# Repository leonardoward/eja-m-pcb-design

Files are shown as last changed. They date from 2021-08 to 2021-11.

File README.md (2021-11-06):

# EJA M v1.0

<p align="center">
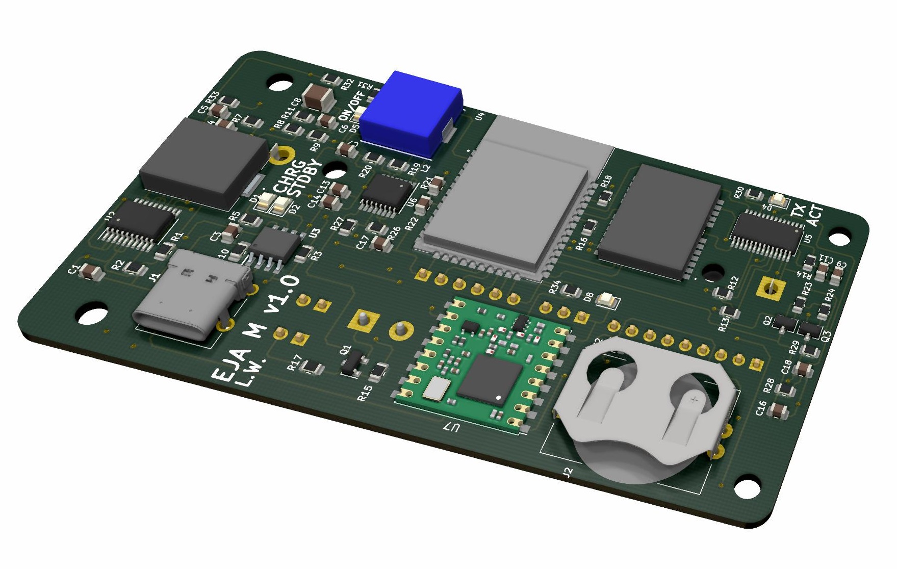
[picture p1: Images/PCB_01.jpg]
  
</p>

The new EJA M v1.0 is an upgrade/replacement of my older PCB designs: [Buoy A v1.0](https://github.com/leonardoward/eja-intelligent-buoy-a-electronics), [Buoy B v1.0](https://github.com/leonardoward/eja-intelligent-buoy-b-electronics), and [Onboard Gateway v1.0](https://github.com/leonardoward/eja-onboard-gateway-electronics). The design includes the following features:

- USB C Port with Electromagnetic Compatibility (EMC)
- FTDI (FT260S-U) with an Auto Reset Circuit for the ESP32
- ESP32
- GPS Module
- LoRa Transceiver
- Real-time Clock (RTC)
- Connector for a Servo Motor
- 5V 2A Stepup (for the Servo Motor)
- 3.3V Battery Charging Circuit
- Connector for a 3 axis accelerometer
- Circuit to measure the battery level
- 3.3V 3A SEPIC Converter
- On-OFF circuit for a Button
- Access to unused pins in the ESP32

This repository contains the Kicad project (including Gerber files) and a more detailed description about the implementation of the different features in the design.

## Table of Contents

1. [Hardware Design](#getting-started)
    1. [USB C Port with Electromagnetic Compatibility EMC](#usb-c-port-with-electromagnetic-compatibility-emc)
    2. [FTDI FT260S](#ftdi-ft260s)
    3. [Auto Reset Circuit for the ESP32](#auto-reset-circuit-for-the-esp32)
    4. [ESP32](#esp32)
    5. [GPS](#gps)
    6. [LoRa](#lora)
    7. [Real time Clock RTC](#real-time-clock-rtc)
    8. [Servo Motor Connector](#servo-motor-connector)
    9. [5V 2A Stepup](#5v-2a-stepup)
    10. [Accelerometer Connector](#accelerometer-connector)
    11. [Battery Charging Circuit](#battery-charging-circuit)
    12. [Battery Level](#battery-level)
    13. [3V3 3A SEPIC Converter](#3v3-3a-sepic-converter)
    14. [ON-OFF Led](#on-off-led)
    15. [ON-OFF Button Circuit](#on-off-button-circuit)
    16. [Extra Header](#extra-header)
2. [PCB Dimensions and Boundaries](#pcb-dimensions-and-boundaries)
3. [3D Model](#3d-model)
4. [Bill of Materials](#bill-of-materials)
    1. [PCB Components](#pcb-components)
    2. [Externals Components](#externals-components)

## Hardware Design

### USB C Port with Electromagnetic Compatibility EMC

Everything starts with the USB C port, we have chosen this type of USB because it's size and because of the growing trend of using this port to charge and communicate with portable devices.

We have included [Transient Voltage Suppression (TVS) diodes](https://www.digikey.com/en/products/detail/comchip-technology/CPDT6-5V4-HF/1121118) and [Ferrite Beads](https://www.digikey.com/en/products/detail/fair-rite-products-corp/2508056017Y0/8594301) to reduce the Electromagnetic Interference (EMI). These [protections for the USB port](https://www.rs-online.com/designspark/usb-port-protection) will add compliance with the [EMC regulations and standards](https://learnemc.com/emc-regulations-and-standards) from the  Federal Communications Commission (FCC) and the European Union.   

<p align="center">
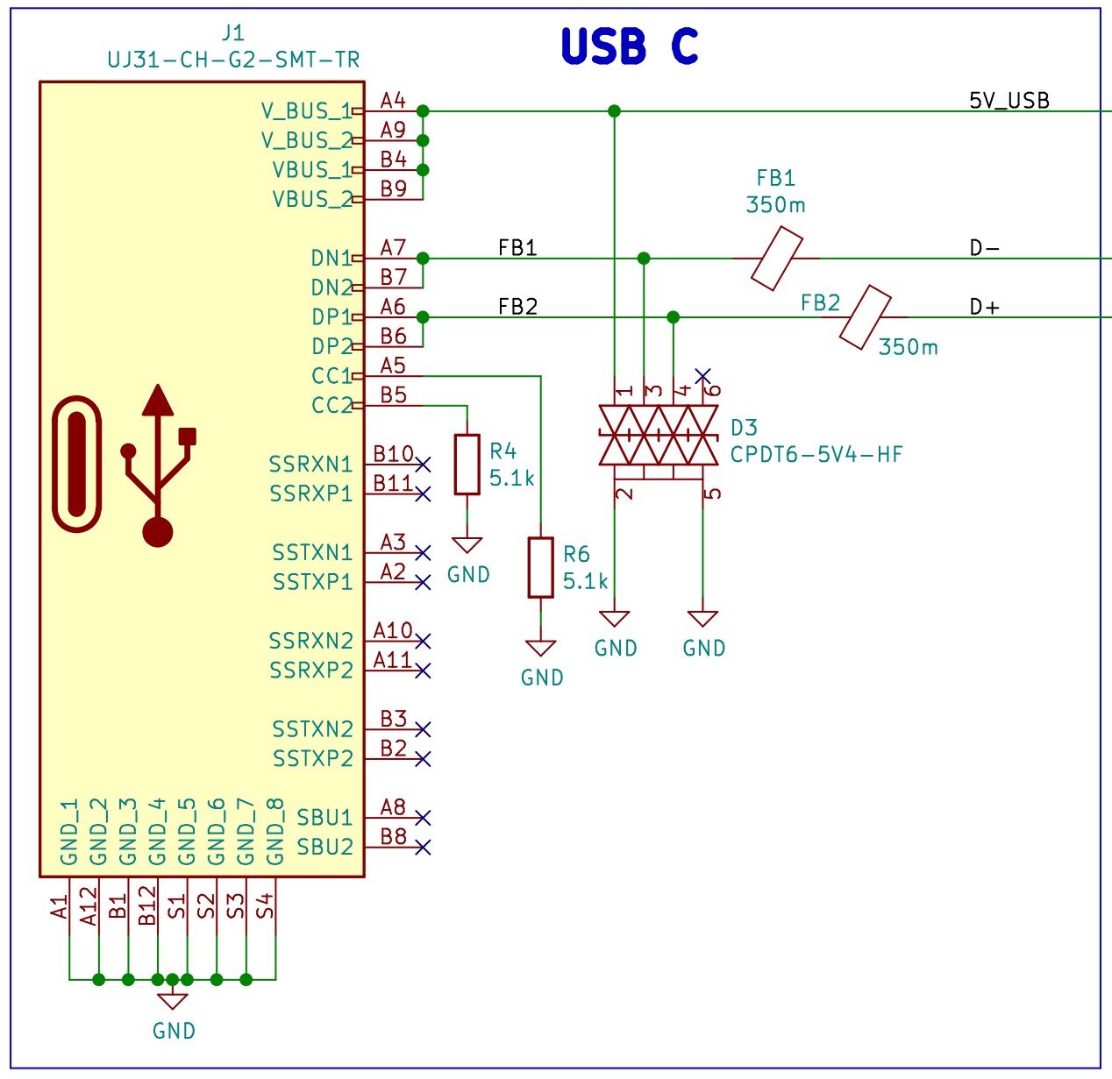
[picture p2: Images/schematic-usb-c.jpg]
  
</p>

**[Back to top](#table-of-contents)**

### FTDI FT260S

The design includes the [FT260S-U](https://www.digikey.com/en/products/detail/ftdi-future-technology-devices-international-ltd/FT260S-U/6124909), a USB TO UART/I2C FTDI that will be used to program the ESP32.

<p align="center">
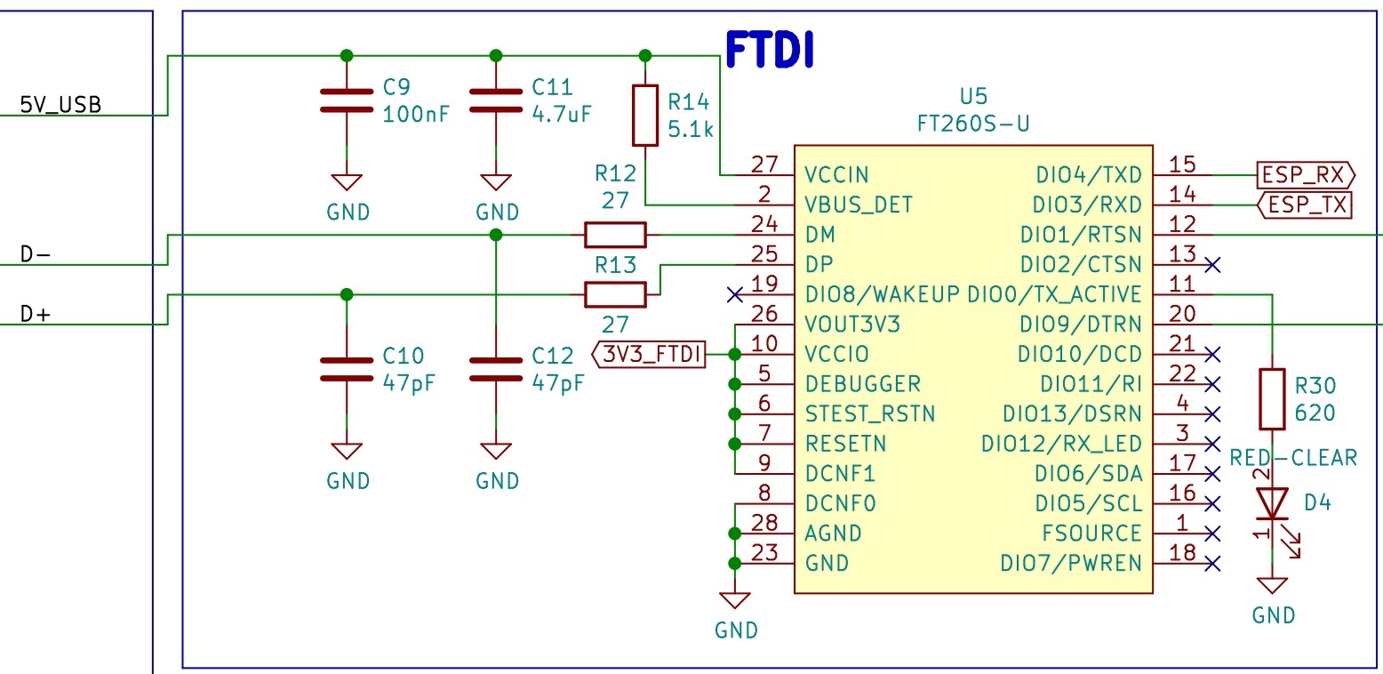
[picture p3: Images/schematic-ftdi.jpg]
  
</p>

**[Back to top](#table-of-contents)**

### Auto Reset Circuit for the ESP32

The design includes an auto reset circuit that uses RTS and DTR to reset and put in bootloader mode the [ESP32](https://www.digikey.com/en/products/detail/espressif-systems/ESP32-WROOM-32D-4MB/9381716). For more information about this circuit, these blogs [(1)](https://forum.micropython.org/viewtopic.php?f=18&t=4966) [(2)](https://forums.adafruit.com/viewtopic.php?f=57&p=483993#p487891) can be useful.

<p align="center">
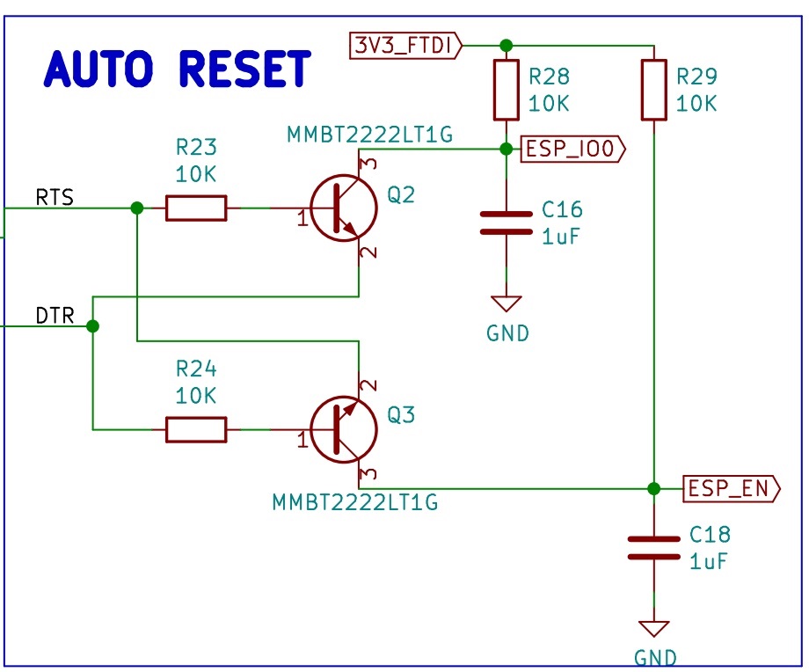
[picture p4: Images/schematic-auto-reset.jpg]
  
</p>

**[Back to top](#table-of-contents)**

### ESP32

The main microcontroller in the PCB is the [ESP32](https://www.digikey.com/en/products/detail/espressif-systems/ESP32-WROOM-32D-4MB/9381716), the following image shows the signals dedicated to the different pins. The ESP32 is connected to the [FTDI](https://www.digikey.com/en/products/detail/ftdi-future-technology-devices-international-ltd/FT260S-U/6124909), a [GPS](https://lcsc.com/product-detail/Satellite-Positioning-Modules_ZHONGKEWEI-ATGM332D-5N31_C128659.html), a [LoRa transceiver](https://www.digikey.com/en/products/detail/rf-solutions/RFM95W-915S2/6564923), a connector for a servo motor, a [real-time clock](https://www.digikey.com/en/products/detail/maxim-integrated/DS3231M-TRL/2402421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), a circuit to measure the battery level, a connector for an [accelerometer](https://www.digikey.com/en/products/detail/adafruit-industries-llc/4097/9951931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), and a few headers to provide access for the unused peripherals.

<p align="center">
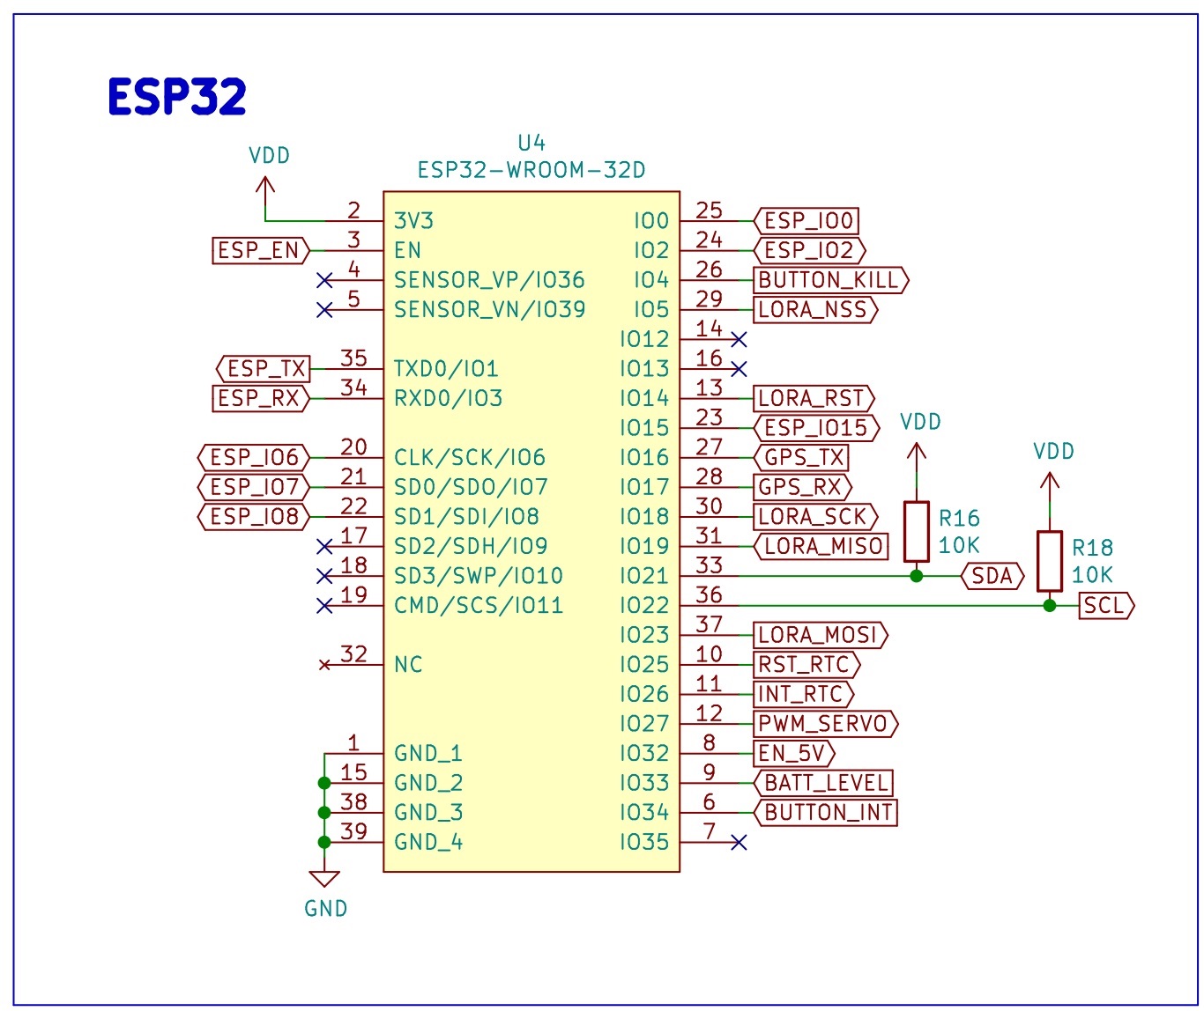
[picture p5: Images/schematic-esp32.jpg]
  
</p>

**[Back to top](#table-of-contents)**

### GPS

The selected GPS is the [ATGM332D-5N31](https://lcsc.com/product-detail/Satellite-Positioning-Modules_ZHONGKEWEI-ATGM332D-5N31_C128659.html), one the modules tested previously in our [Development Board for GPS Modules](https://hackaday.io/project/173457-2021-hdp-dream-team-eja/log/196269-gps-antenova-m20050-1-and-atgm332d-5n31-dev-board). The schematic is very simple, it has a decoupling capacitors (C2), a [U.FL connector](https://www.digikey.com/en/products/detail/hirose-electric-co-ltd/U-FL-R-SMT-1-10/2391570) for an external antenna (J4) and a [Coin Cell Battery Holder](https://www.digikey.com/en/products/detail/linx-technologies-inc/BAT-HLD-001-THM/3044009) (J2).

<p align="center">
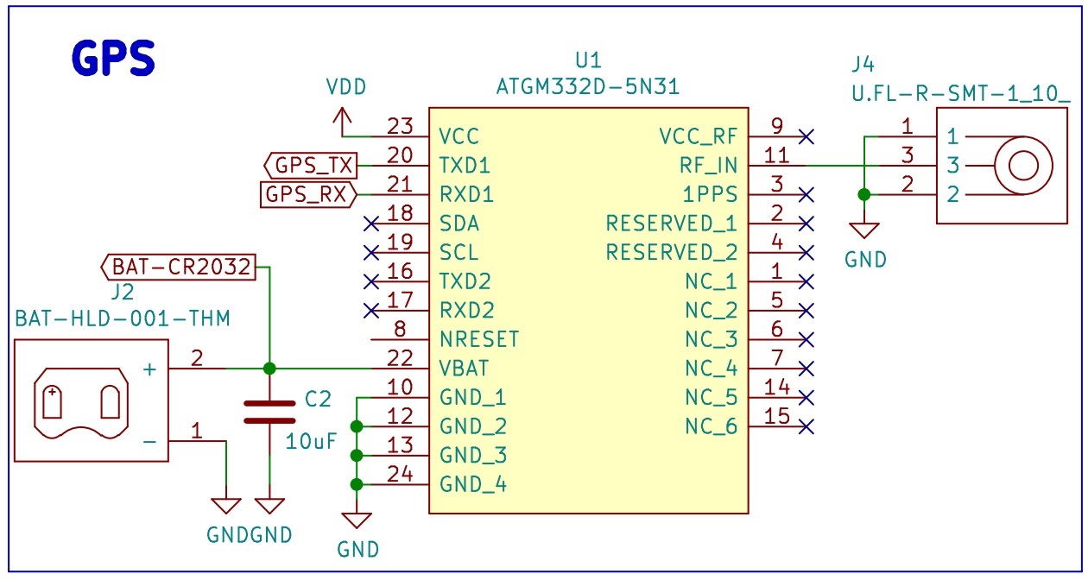
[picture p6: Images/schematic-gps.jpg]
  
</p>

**[Back to top](#table-of-contents)**

### LoRa

The selected LoRa transceiver is the [RFM95W-915S2](https://www.digikey.com/en/products/detail/rf-solutions/RFM95W-915S2/6564923), the same module tested in our [Development Board for LoRa](https://hackaday.io/project/173457-2021-hdp-dream-team-eja/log/196116-lora-rfm95w-915s2-development-board). The schematic contains a [U.FL connector](https://www.digikey.com/en/products/detail/hirose-electric-co-ltd/U-FL-R-SMT-1-10/2391570) for an external antenna (J9).

<p align="center">
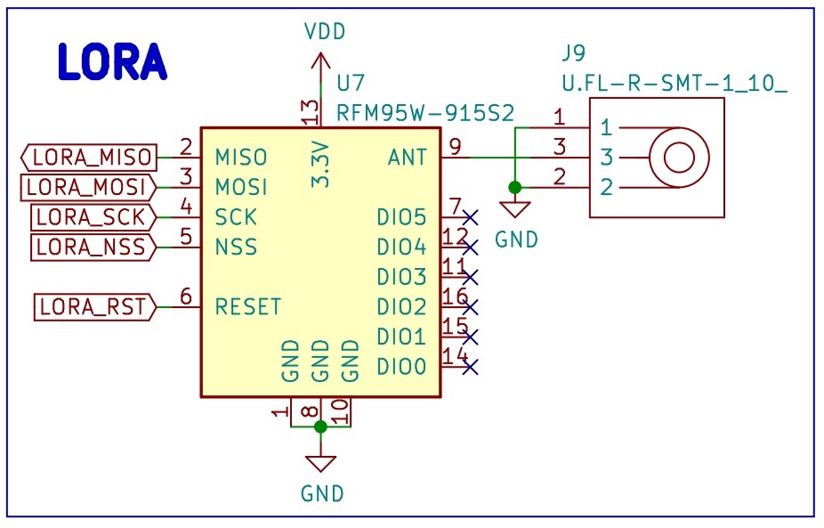
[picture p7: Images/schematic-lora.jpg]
  
</p>

**[Back to top](#table-of-contents)**

### Real time Clock RTC

The design includes a dedicated RTC, the [DS3231M](https://www.digikey.com/en/products/detail/maxim-integrated/DS3231M-TRL/2402421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).

<p align="center">
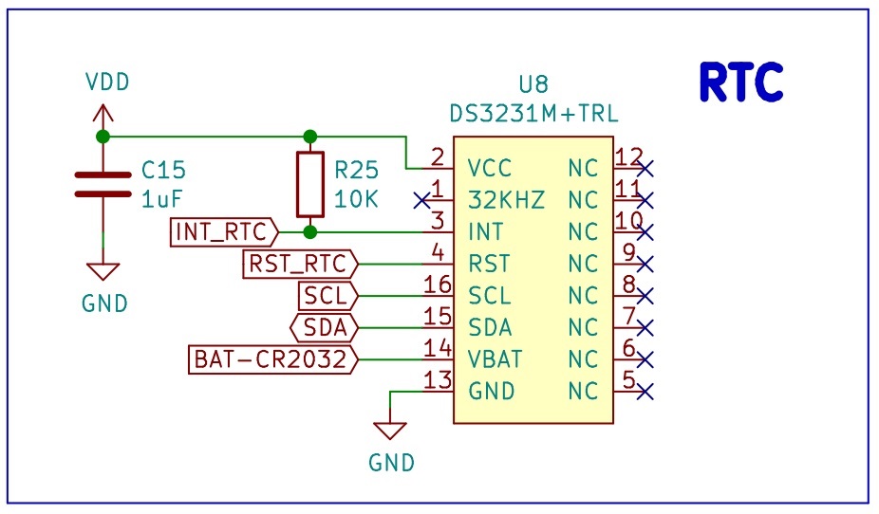
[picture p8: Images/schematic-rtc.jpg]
  
</p>

**[Back to top](#table-of-contents)**

### Servo Motor Connector

There is a 1x3 header connector for a Servo Motor, the 5V for the servo is provided by a 5V 2A Stepup.

<p align="center">
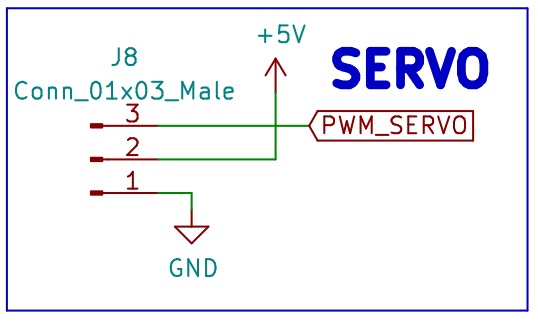
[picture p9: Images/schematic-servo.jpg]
  
</p>

**[Back to top](#table-of-contents)**

### 5V 2A Stepup

The design includes the [TPS61030PWR](http://digikey.com/en/products/detail/texas-instruments/TPS61030PWPR/550685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), a boost converter with a 4A switch current, to provide the 5V for the Servo motor. The schematic contains the components for a 5V 2A output, following the design procedure that starts on the page 13 in the datasheet.

<p align="center">
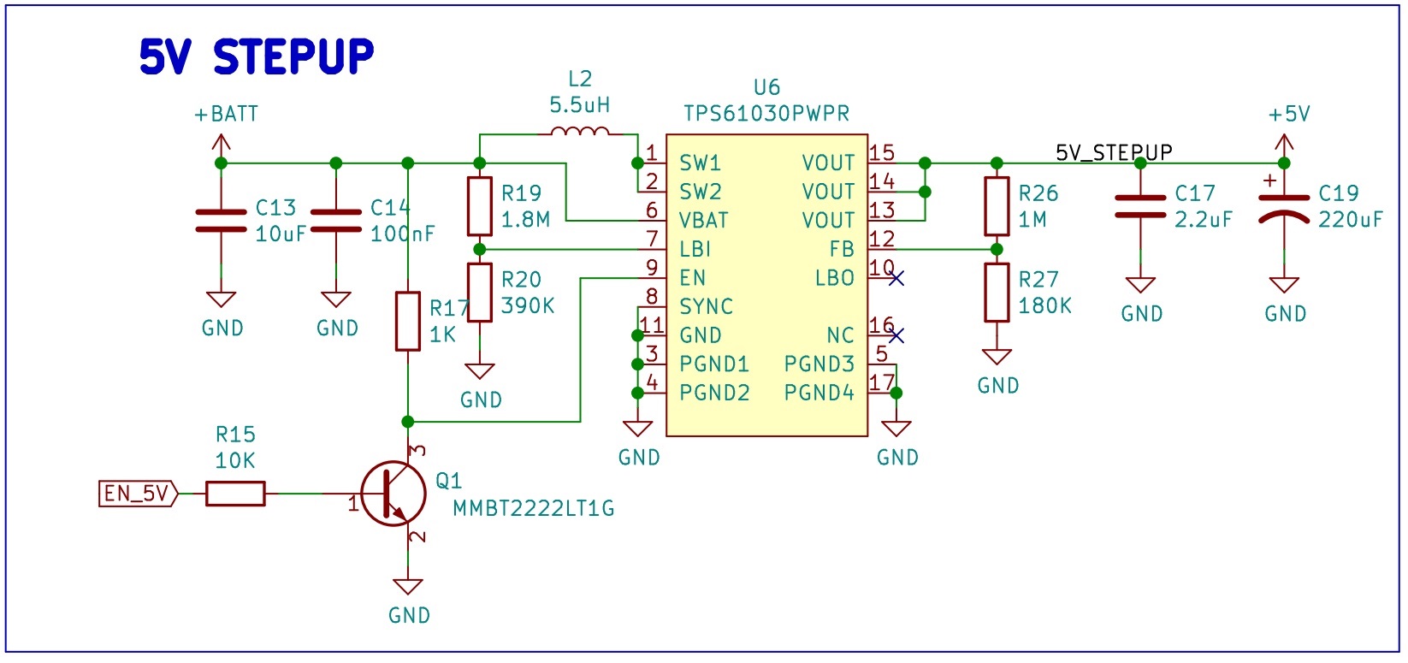
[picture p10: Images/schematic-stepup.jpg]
  
</p>

**[Back to top](#table-of-contents)**

### Accelerometer Connector

There is a connector for the [ADXL343 3 axis accelerometer](https://www.digikey.com/en/products/detail/adafruit-industries-llc/4097/9951931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), a 1x9 header was used even though it only manages the signals VDD, GND, SCL and SDA, in case we want to use more connections for the accelerometer in future versions.

<p align="center">
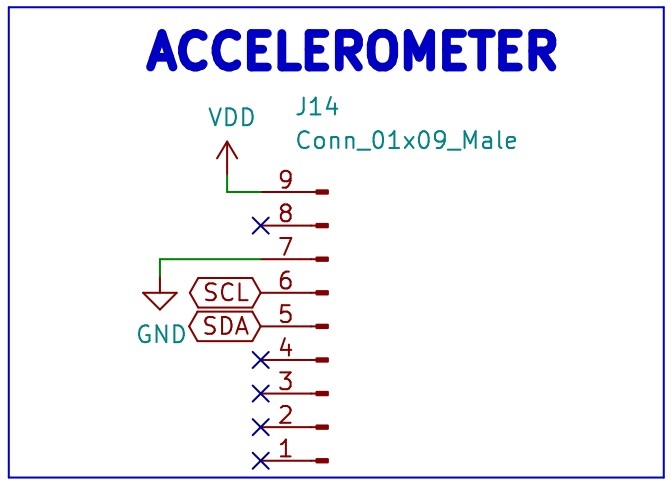
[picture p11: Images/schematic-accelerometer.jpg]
  
</p>

**[Back to top](#table-of-contents)**

### Battery Charging Circuit

To charge the 3.3V battery the design includes the [TP4056](https://www.lcsc.com/product-detail/Battery-Management-ICs_TPOWER-TP4056_C382139.html), a 1A Standalone Linear Li-lon Battery Charger. The schematic includes a green led to show the user that the battery is charged and a red led to show the user that the battery is charging. There is a [Battery Holder for a 18650 battery](https://www.digikey.com/en/products/detail/mpd-memory-protection-devices/BH-18650-PC/3029216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) (J5) and an additional 1x2 header (J7) in case we want to use a different 3.3V battery.  There is also a 1x2 header (J3) to use a different type of connection for the charger (instead of the USB C), for example we can connect and test a QI Wireless Charger.

<p align="center">
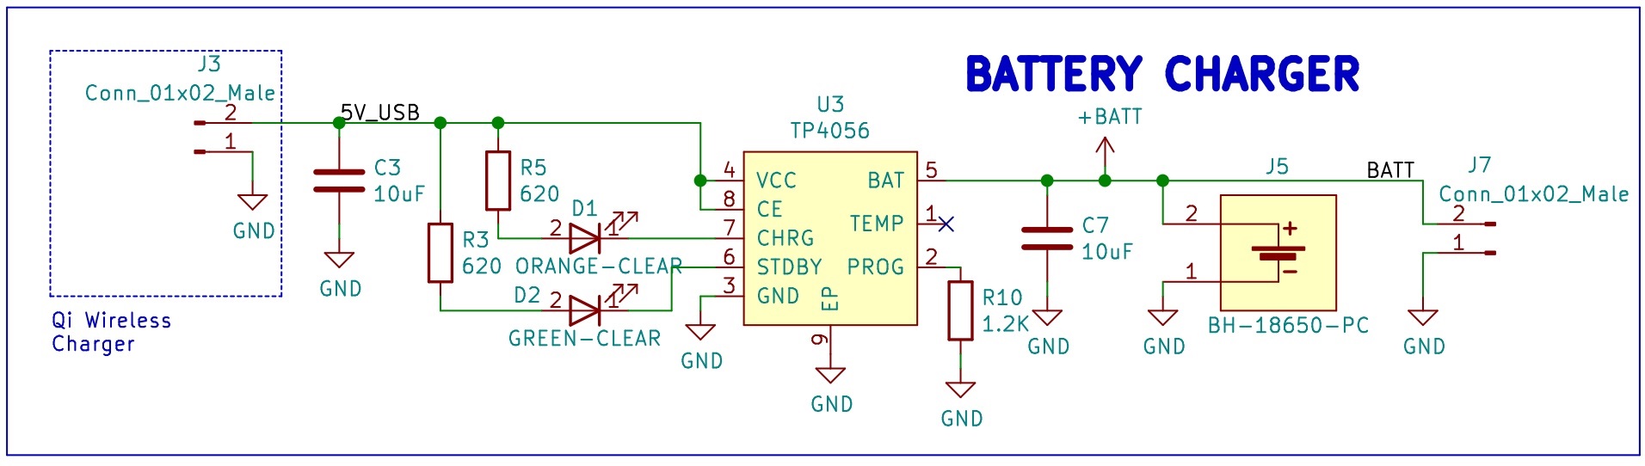
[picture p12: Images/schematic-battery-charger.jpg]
  
</p>

**[Back to top](#table-of-contents)**

### Battery Level

The design contains a circuit to measure a battery level, it is a simple resistor divider calculated for a range of 2.7V to 4.2V, the normal range for the 18650 Li-Ion Battery that will be used in the design.

<p align="center">
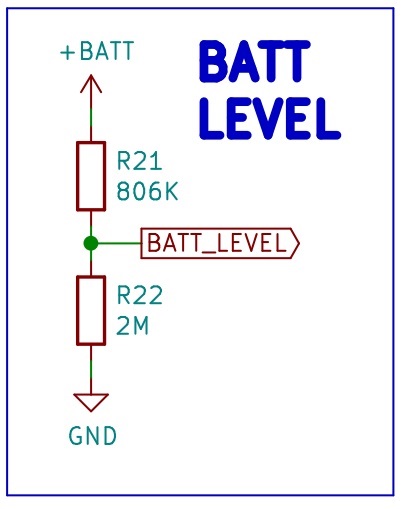
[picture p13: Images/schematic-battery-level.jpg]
  
</p>

Those values for the resistor divider give the following range for the ADC:

- Maximum voltage: 4.2V * (2M / (0.806M + 2M)) = 2.99V
- Minimum voltage: 2.7V * (2M / (0.806M + 2M)) = 1.92V

That means that the ADC from the ESP32 will be reading analog values from 1.92V to 2.99V from the battery measurement circuit.

For more information about measuring lithium battery voltage visit the following [link](https://devzone.nordicsemi.com/nordic/nordic-blog/b/blog/posts/measuring-lithium-battery-voltage-with-nrf52).

**[Back to top](#table-of-contents)**

### 3V3 3A SEPIC Converter

Since the voltage of the battery can change from 2.7V (discharged) to 4.2V (charged), a SEPIC converter is included to provide a constant 3.3V to the digital circuits regardless of the changes in the input voltage from the battery. The selected SEPIC converter is the [LTC3113EFE#TRPBF](https://www.digikey.com/en/products/detail/analog-devices-inc/LTC3113EFE-TRPBF/2521714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).

<p align="center">
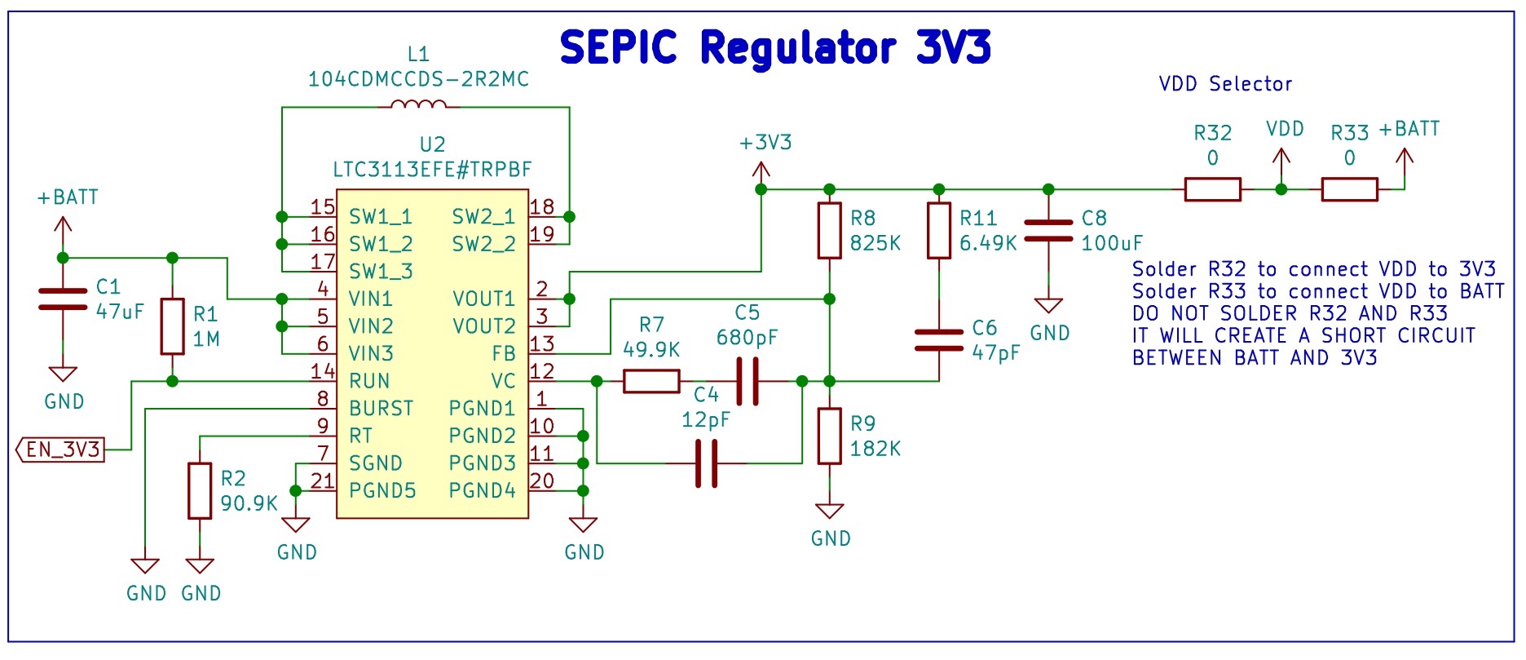
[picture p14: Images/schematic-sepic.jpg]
  
</p>

**Note**: The resistor R32 is a jumper that connects VDD to 3V3. R33 is a jumper that connects VDD to the battery. Do not solder both at the same time, it will create a short circuit between 3.3V from the SEPIC and the voltage from the battery. R32 and R33 are included just in case the SEPIC converter doesn't work and we have to connect the circuit directly to the battery.

**Summary: Do not solder R33**.

**[Back to top](#table-of-contents)**

### ON-OFF Led

There is  Green Led that turns on with the 3.3V from the SEPIC converter, it will notify the user/developer that the device is ON or OFF.

<p align="center">
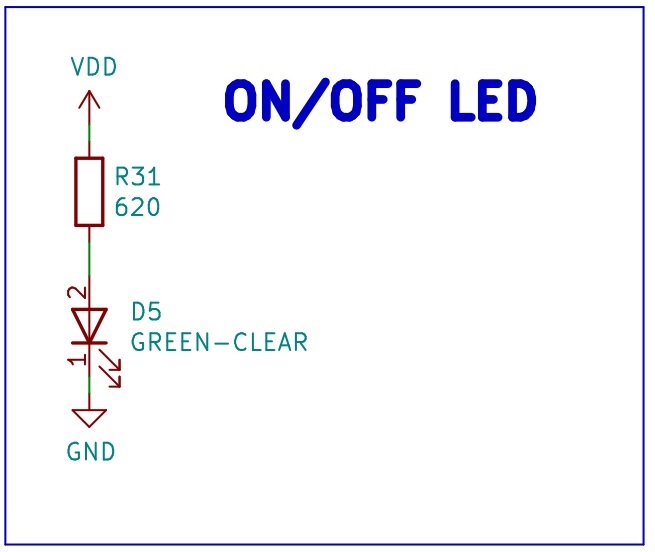
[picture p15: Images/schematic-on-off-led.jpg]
  
</p>

**[Back to top](#table-of-contents)**

### ON-OFF Button Circuit

The design contains a [LTC2954ITS8-1#TRPBF](https://www.digikey.com/en/products/detail/analog-devices-inc/LTC2954ITS8-1-TRPBF/1621452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), a pushbutton ON/OFF controller that manages the power supply (enables the 3.3V SEPIC) via a pushbutton interface.

<p align="center">
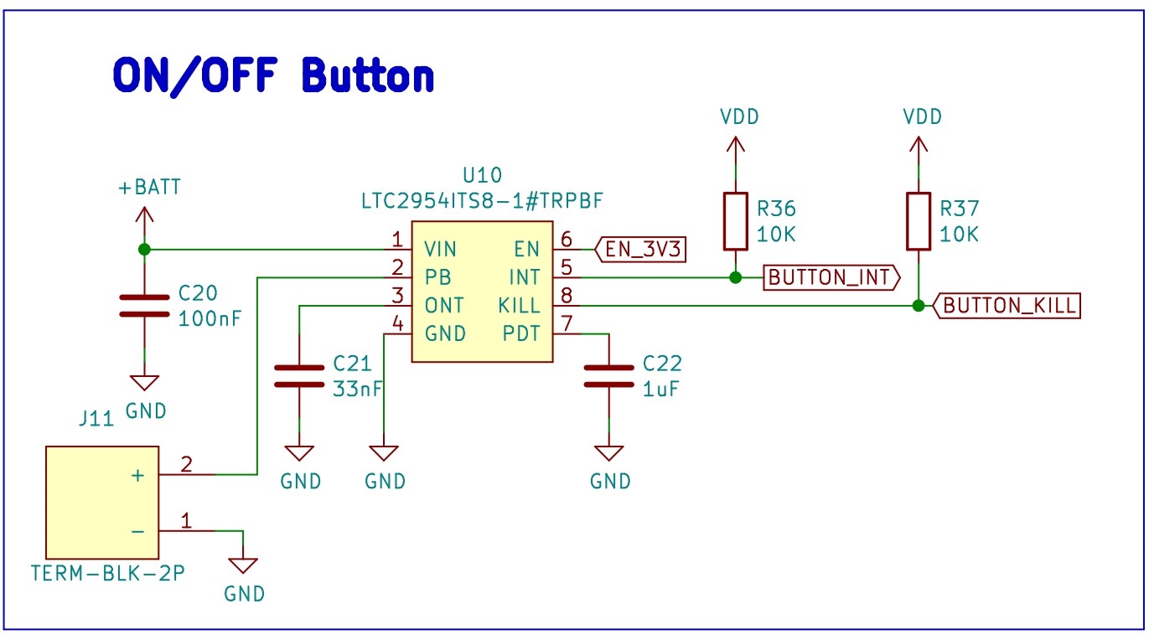
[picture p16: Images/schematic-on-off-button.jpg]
  
</p>

**[Back to top](#table-of-contents)**

### Extra Header

The design includes an 1x06 header to provide access for some of the unused pins in the ESP32.

<p align="center">
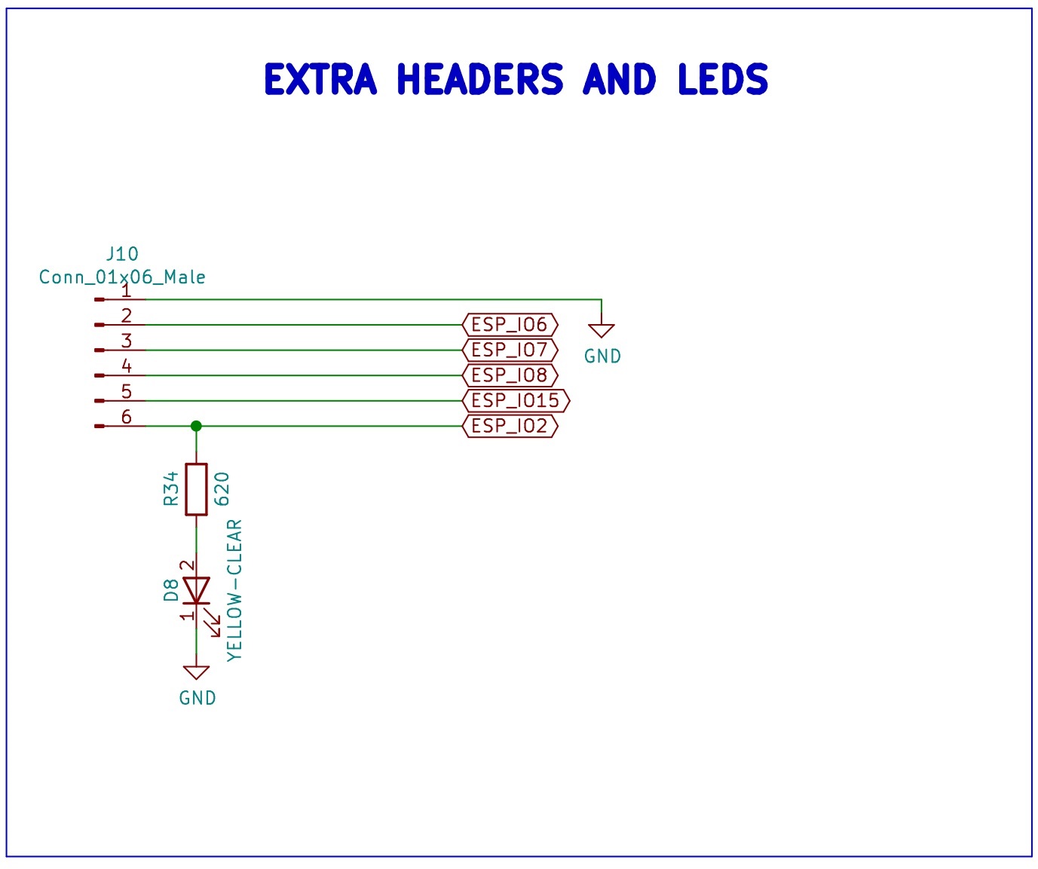
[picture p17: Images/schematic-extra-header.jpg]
  
</p>

**[Back to top](#table-of-contents)**

## PCB Dimensions and Boundaries

The dimensions of the PCB are dictated by the maximum available space inside the buoy, from the enclosure design we where able to define the size of the PCB: 97.5 mm x 51.2 mm.

In the back layer there is a restricted region, that can't contain any components because the PCB is directly in contact with the enclosure in that region, those are the boundaries of the back layer. Through hole footprints where not be placed in that section, even if the footprint is placed in the front layer.

<p align="center">
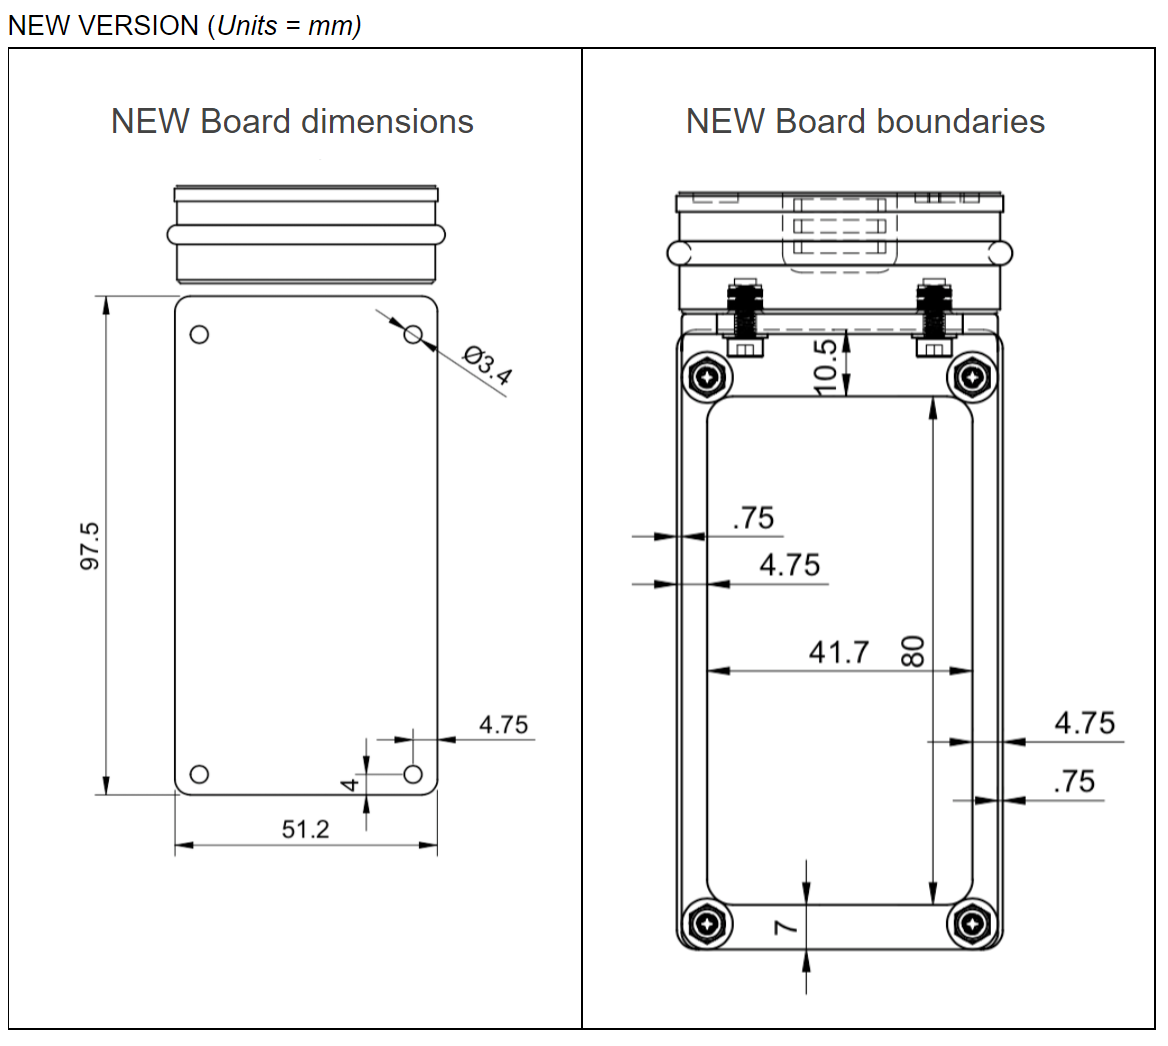
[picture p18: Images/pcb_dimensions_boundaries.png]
  
</p>

**[Back to top](#table-of-contents)**

## 3D Model

The following images show the front and back layers of the PCB.

<p align="center">
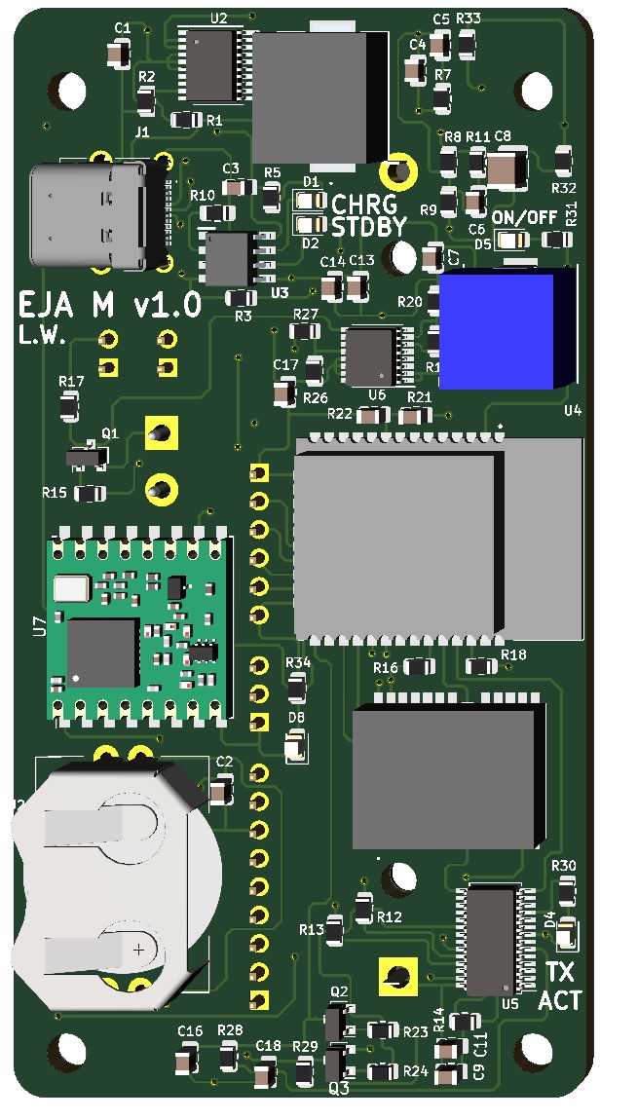
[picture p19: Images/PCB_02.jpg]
  
</p>

<p align="center">
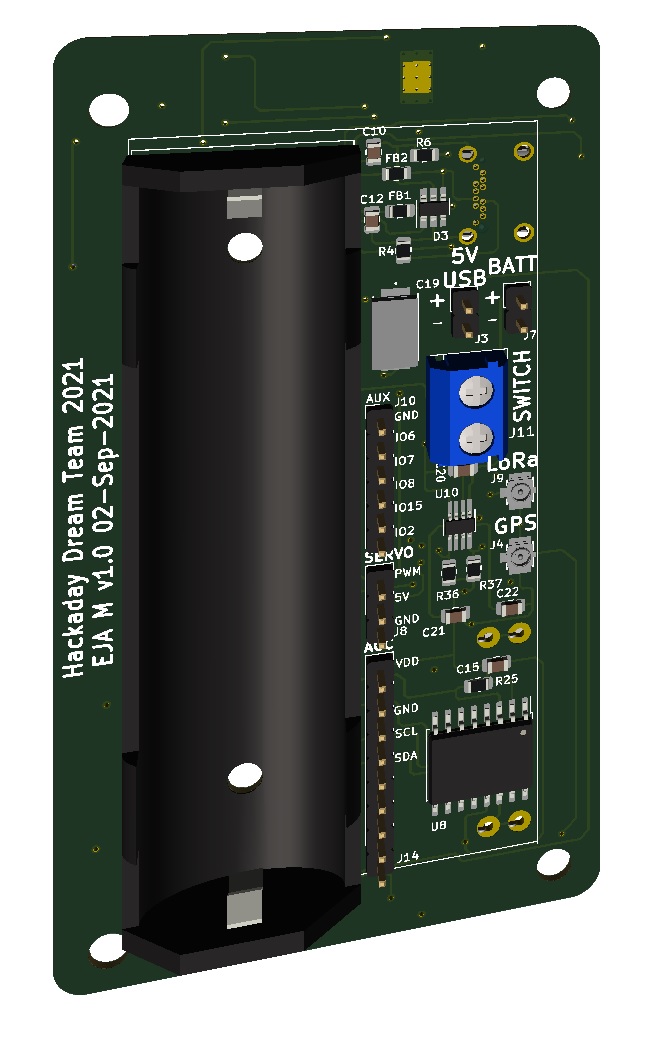
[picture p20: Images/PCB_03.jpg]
  
</p>

**[Back to top](#table-of-contents)**

## Bill of Materials

### PCB Components

| Reference | Quantity |
| --- | --- |
| [PCB](https://www.pcbway.com/)  | 1 |
| [47 µF ±20% 6.3V Ceramic Capacitor 0805](https://www.digikey.com/en/products/detail/taiyo-yuden/JMK212BBJ476MG-T/4970731)  | 1 |
| [10 µF ±10% 6.3V Ceramic Capacitor 0805](https://www.digikey.com/en/products/detail/samsung-electro-mechanics/CL21A106KQCLNNC/3888062)  | 4 |
| [12 pF ±5% 50V Ceramic Capacitor 0805](https://www.digikey.com/en/products/detail/stackpole-electronics-inc/CML0805C0G120JT50V/10660016)  | 1 |
| [680 pF ±10% 25V Ceramic Capacitor 0805](https://www.digikey.com/en/products/detail/w%C3%BCrth-elektronik/885012207059/5455614)  | 1 |
| [47 pF ±5% 16V Ceramic Capacitor 0805](https://www.digikey.com/en/products/detail/w%C3%BCrth-elektronik/885012007014/5453673)  | 3 |
| [100 µF ±20% 6.3V Ceramic Capacitor 1210](https://www.digikey.com/en/products/detail/murata-electronics/GRM32EE70J107ME15L/5027618)  | 1 |
| [0.1 µF ±10% 50V Ceramic Capacitor 0805](https://www.digikey.com/en/products/detail/avx-corporation/08055C104KAT2A/563505)  | 3 |
| [4.7 µF ±10% 6.3V Ceramic Capacitor 0805](https://www.digikey.com/en/products/detail/samsung-electro-mechanics/CL21A475KQFNNNE/3886856)  | 1 |
| [1 µF ±10% 16V Ceramic Capacitor 0805](https://www.digikey.com/en/products/detail/yageo/CC0805KKX7R7BB105/2103103)  | 4 |
| [2.2 µF ±10% 10V Ceramic Capacitor 0805](https://www.digikey.com/en/products/detail/samsung-electro-mechanics/CL21B225KPFNNNE/3886846)  | 1 |
| [220 µF Tantalum Capacitors 10V 2917](https://www.digikey.com/en/products/detail/nemco/PCT220-10HK/13236441)  | 1 |
| [0.033 µF ±10% 50V Ceramic Capacitor 0805](https://www.digikey.com/en/products/detail/w%C3%BCrth-elektronik/885012207095/5453932)  | 1 |
| [Orange 601nm LED - Discrete 2.1V 0805](https://www.digikey.com/en/products/detail/sunled/XZMOK54W-1/4745796)  | 1 |
| [Green 520nm LED - Discrete 3.2V 0805](https://www.digikey.com/en/products/detail/w%C3%BCrth-elektronik/150080GS75000/4489915)  | 2 |
| [TVS Diode 15V Clamp 5A (8/20µs) SOT-23-6](https://www.digikey.com/en/products/detail/comchip-technology/CPDT6-5V4-HF/1121118)  | 1 |
| [Red 630nm LED - Discrete 1.9V 0805](https://www.digikey.com/en/products/detail/w%C3%BCrth-elektronik/150080SS75000/4489921)  | 1 |
| [Yellow 590nm LED - Discrete 2V 0805](https://www.digikey.com/en/products/detail/everlight-electronics-co-ltd/QTLP630C3TR/2675901)  | 1 |
| [1 Signal Line Ferrite Bead 0805 300mA 350mOhm](https://www.digikey.com/en/products/detail/fair-rite-products-corp/2508056017Y0/8594301)  | 2 |
| [USB-C USB 3.2 Gen 2 Receptacle Connector](https://www.digikey.com/en/products/detail/cui-devices/UJ31-CH-G2-SMT-TR/8024057)  | 1 |
| [Battery Retainer Coin, 20.0mm 1 Cell PC Pin](https://www.digikey.com/en/products/detail/linx-technologies-inc/BAT-HLD-001-THM/3044009)  | 1 |
| [U.FL (UMCC) Connector Receptacle](https://www.digikey.com/en/products/detail/hirose-electric-co-ltd/U-FL-R-SMT-1-10/2391570)  | 2 |
| [Battery Holder (Open) 18650 1 Cell PC Pin](https://www.digikey.com/en/products/detail/mpd-memory-protection-devices/BH-18650-PC/3029216)  | 1 |
| [2 Position Terminal Block Horizontal](https://www.digikey.com/en/products/detail/on-shore-technology-inc/OSTTC022162/614558)  | 1 |
| [2.2 µH Inductor 15 A 7mOhm Max](https://www.digikey.com/en/products/detail/sumida-america-components-inc/104CDMCCDS-2R2MC/5812436)  | 1 |
| [5.5 µH Inductor 10 A 10.3mOhm](https://www.digikey.com/en/products/detail/w%C3%BCrth-elektronik/744325550/1638576)  | 1 |
| [Bipolar (BJT) Transistor NPN 30V 600mA SOT-23-3](https://www.digikey.com/en/products/detail/onsemi/MMBT2222LT1G/919595)  | 3 |
| [1 MOhms ±1% 0.125W Chip Resistor 0805](https://www.digikey.com/en/products/detail/stackpole-electronics-inc/RMCF0805FT1M00/1760080)  | 2 |
| [90.9 kOhms ±1% 0.125W Chip Resistor 0805](https://www.digikey.com/en/products/detail/stackpole-electronics-inc/RMCF0805FT90K9/1760265)  | 1 |
| [620 Ohms ±5% 0.125W Chip Resistor 0805](https://www.digikey.com/en/products/detail/yageo/RC0805JR-07620RL/728357)  | 5 |
| [5.1 KOhms ±1% 0.125W Chip Resistor 0805](https://www.digikey.com/en/products/detail/stackpole-electronics-inc/RMCF0805FT5K10/1760394)  | 3 |
| [49.9 KOhms ±1% 0.125W Chip Resistor 0805](https://www.digikey.com/en/products/detail/stackpole-electronics-inc/RMCF0805FT49K9/1760272)  | 1 |
| [825 kOhms ±0.5% 0.125W Chip Resistor 0805](https://www.digikey.com/en/products/detail/panasonic-electronic-components/ERA-6AED8253V/3481309)  | 1 |
| [182 kOhms ±1% 0.25W Chip Resistor 0805](https://www.digikey.com/en/products/detail/koa-speer-electronics-inc/RK73H2ATTD1823F/10234151)  | 1 |
| [1.2 kOhms ±5% 0.125W Chip Resistor 0805](https://www.digikey.com/en/products/detail/yageo/RC0805JR-071K2L/728224)  | 1 |
| [6.49 kOhms ±1% 0.125W Chip Resistor 0805](https://www.digikey.com/en/products/detail/panasonic-electronic-components/ERJ-6ENF6491V/111437)  | 1 |
| [27 Ohms ±1% 0.125W Chip Resistor 0805](https://www.digikey.com/en/products/detail/stackpole-electronics-inc/RMCF0805FT27R0/1712920)  | 2 |
| [10 kOhms ±1% 0.125W Chip Resistor 0805](https://www.digikey.com/en/products/detail/vishay-dale/CRCW080510K0FKEAC/7928398)  | 10 |
| [1 kOhms ±1% 0.125W Chip Resistor 0805](https://www.digikey.com/en/products/detail/stackpole-electronics-inc/RMCF0805FT1K00/1760090)  | 1 |
| [1.8 MOhms ±1% 0.125W Chip Resistor 0805](https://www.digikey.com/en/products/detail/panasonic-electronic-components/ERJ-6ENF1804V/282715)  | 1 |
| [390 kOhms ±1% 0.125W Chip Resistor 0805](https://www.digikey.com/en/products/detail/yageo/RC0805FR-07390KL/727903)  | 1 |
| [806 kOhms ±1% 0.125W Chip Resistor 0805](https://www.digikey.com/en/products/detail/panasonic-electronic-components/ERJ-6ENF8063V/112197)  | 1 |
| [2 MOhms ±1% 0.125W Chip Resistor 0805](https://www.digikey.com/en/products/detail/vishay-dale/CRCW08052M00FKECC/7928551)  | 1 |
| [180 kOhms ±0.5% 0.1W Chip Resistor 0805](https://www.digikey.com/en/products/detail/susumu/RR1220P-184-D/432345)  | 1 |
| [0 Ohms Jumper 0.125W Chip Resistor 0805](https://www.digikey.com/en/products/detail/yageo/RC0805JR-070RL/728216)  | 2 |
| [ATGM332D-5N31 GNSS Series GPS+BDS 12.2x16x2.4mm](https://www.lcsc.com/product-detail/Satellite-Positioning-Modules_ZHONGKEWEI-ATGM332D-5N31_C128659.html)  | 1 |
| [Buck-Boost Switching Regulator 1.8V 1 Output 3A](https://www.digikey.com/en/products/detail/analog-devices-inc/LTC3113EFE-TRPBF/2521714)  | 1 |
| [TP4056 ESOP-8 Battery Management](https://www.lcsc.com/product-detail/Battery-Management-ICs_TPOWER-TP4056_C382139.html)  | 1 |
| [ESP32-WROOM-32D (4MB)](https://www.digikey.com/en/products/detail/espressif-systems/ESP32-WROOM-32D-4MB/9381716)  | 1 |
| [FTDI USB Bridge, USB to I²C/UART USB 2.0 I²C, UART Interface 28-TSSOP](https://www.digikey.com/en/products/detail/ftdi-future-technology-devices-international-ltd/FT260S-U/6124909)  | 1 |
| [TPS61030PWPR Boost Switching Regulator IC Positive Adjustable 1.8V 1 Output 3.6A (Switch)](https://www.digikey.com/en/products/detail/texas-instruments/TPS61030PWPR/550685)  | 1 |
| [RFM95W-915S2-ND LoRa Transceiver Module 915MHz](https://www.digikey.com/en/products/detail/rf-solutions/RFM95W-915S2/6564923)  | 1 |
| [DS3231M+TRL Real Time Clock I²C, 2-Wire Serial](https://www.digikey.com/en/products/detail/maxim-integrated/DS3231M-TRL/2402421)  | 1 |
| [Power Supply On/Off Controller Push Button](https://www.digikey.com/en/products/detail/analog-devices-inc/LTC2954ITS8-1-TRPBF/1621452)  | 1 |
| [Connector Header Through Hole 40 position (2.54mm)](https://www.digikey.com/en/products/detail/sullins-connector-solutions/PREC040SFAN-RC/2774934)  | 1 |

### Externals Components

| Reference | Quantity |
| --- | --- |
| [SERVOMOTOR RC 5V HIGH TORQUE](https://www.digikey.com/products/es?keywords=1528-1084-ND)  | 1 |
| [CR2032 Lithium Coin Cell Battery](https://www.adafruit.com/product/654)  | 1 |
| [18650 Lithium-Ion 3.7V Battery Rechargeable 3.4Ah](https://www.digikey.com/en/products/detail/ultralast/LION-1865-34/13692714)  | 1 |
| [ADXL343 - Triple-Axis Accelerometer](https://www.digikey.com/en/products/detail/adafruit-industries-llc/4097/9951931)  | 1 |

For more information about the BOM including prices and different comparisons with my previous designs visit the following [link](https://hackaday.io/project/173457-2021-hdp-dream-team-eja/log/198071-eja-m-v10-bill-of-materials).

**[Back to top](#table-of-contents)**

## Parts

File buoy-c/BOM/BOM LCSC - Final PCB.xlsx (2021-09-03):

Reference | Quantity | LCSC Part Number
TP4056 | 4 | C382139
ESP32-WROOM-32D | 2 | C473012

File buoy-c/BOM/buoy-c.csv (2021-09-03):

Source: | C:\Ext\Dream Team 2021\eja-buoy-c-pcb-design\buoy-c\buoy-c.sch
Date: | 02-Sep-21 10:00:40 AM
Tool: | Eeschema (5.1.10)-1
Generator: | C:\Program Files\KiCad\bin\scripting\plugins/bom_csv_grouped_by_value.py
Component Count: | 91
Individual Components:
Item | Qty | Reference(s) | Value | LibPart | Footprint | Datasheet | Description | Field7 | Height | LCSC | Manufacturer | Manufacturer Name | Manufacturer Part Number | Manufacturer_Name | Manufacturer_Part_Number | Supplier 1 | Supplier 2 | Supplier Part Number 1 | Supplier Part Number 2
 |  | C1 | 47uF | C-47uF-0805:47uF | Capacitor_SMD:C_0805_2012Metric | https://www.yuden.co.jp/productdata/catalog/mlcc06_e.pdf |  |  |  |  | Taiyo Yuden |  | JMK212BBJ476MG-T |  |  | Digi-Key |  | 587-4280-1-ND
 |  | C2 | 10uF | C-10uF-0805:10uF | Capacitor_SMD:C_0805_2012Metric |  |  |  |  |  | Samsung Electro-Mechanics |  | CL21A106KQCLNNC |  |  | Digi-Key |  | 1276-2404-1-ND
 |  | C3 | 10uF | C-10uF-0805:10uF | Capacitor_SMD:C_0805_2012Metric |  |  |  |  |  | Samsung Electro-Mechanics |  | CL21A106KQCLNNC |  |  | Digi-Key |  | 1276-2404-1-ND
 |  | C4 | 12pF | C-12pF-0805:12pF | Capacitor_SMD:C_0805_2012Metric | http://www.seielect.com/Catalog/SEI-CML.PDF |  |  |  |  | Stackpole Electronics Inc |  | CML0805C0G120JT50V |  |  | Digi-Key |  | 738-CML0805C0G120JT50VCT-ND
 |  | C5 | 680pF | C-680pF-0805:680pF | Capacitor_SMD:C_0805_2012Metric | https://www.we-online.de/katalog/datasheet/885012207059.pdf |  |  |  |  | Würth Elektronik |  | 885012207059 |  |  | Digi-Key |  | 732-12279-1-ND
 |  | C6 | 47pF | C-47pF-0805:47pF | Capacitor_SMD:C_0805_2012Metric | https://www.we-online.de/katalog/datasheet/885012007014.pdf |  |  |  |  | Würth Elektronik |  |  |  | 885012007014 | Digi-Key |  | 732-7818-1-ND
 |  | C7 | 10uF | C-10uF-0805:10uF | Capacitor_SMD:C_0805_2012Metric |  |  |  |  |  | Samsung Electro-Mechanics |  | CL21A106KQCLNNC |  |  | Digi-Key |  | 1276-2404-1-ND
 |  | C8 | 100uF | C-100uF-1210:100uF | Capacitor_SMD:C_1210_3225Metric | https://search.murata.co.jp/Ceramy/image/img/A01X/G101/ENG/GRM32EE70J107ME15-01.pdf |  |  |  |  | Murata Electronics |  | GRM32EE70J107ME15L |  |  | Digi-Key |  | 490-10534-1-ND
 |  | C9 | 100nF | C-100nF-0805:100nF | Capacitor_SMD:C_0805_2012Metric | https://datasheets.avx.com/X7RDielectric.pdf |  |  |  |  | AVX Corporation |  |  |  | 08055C104KAT2A | Digi-Key |  | 478-1395-1-ND
 |  | C10 | 47pF | C-47pF-0805:47pF | Capacitor_SMD:C_0805_2012Metric | https://www.we-online.de/katalog/datasheet/885012007014.pdf |  |  |  |  | Würth Elektronik |  |  |  | 885012007014 | Digi-Key |  | 732-7818-1-ND
 |  | C11 | 4.7uF | C-4.7uF-0805:4.7uF | Capacitor_SMD:C_0805_2012Metric | http://www.samsungsem.com/kr/support/product-search/mlcc/CL21A475KQFNNNE.jsp |  |  |  |  | Samsung Electro-Mechanics |  |  |  | CL21A475KQFNNNE | Digi-Key |  | 1276-1198-1-ND
 |  | C12 | 47pF | C-47pF-0805:47pF | Capacitor_SMD:C_0805_2012Metric | https://www.we-online.de/katalog/datasheet/885012007014.pdf |  |  |  |  | Würth Elektronik |  |  |  | 885012007014 | Digi-Key |  | 732-7818-1-ND
 |  | C13 | 10uF | C-10uF-0805:10uF | Capacitor_SMD:C_0805_2012Metric |  |  |  |  |  | Samsung Electro-Mechanics |  | CL21A106KQCLNNC |  |  | Digi-Key |  | 1276-2404-1-ND
 |  | C14 | 100nF | C-100nF-0805:100nF | Capacitor_SMD:C_0805_2012Metric | https://datasheets.avx.com/X7RDielectric.pdf |  |  |  |  | AVX Corporation |  |  |  | 08055C104KAT2A | Digi-Key |  | 478-1395-1-ND
 |  | C15 | 1uF | C-1uF-0805:1uF | Capacitor_SMD:C_0805_2012Metric | http://www.samsungsem.com/kr/support/product-search/mlcc/CL21B105KPFNNNE.jsp |  |  |  |  | YAGEO |  | CC0805KKX7R7BB105 |  | CL21B105KPFNNNE | Digi-Key |  | 311-1365-1-ND
 |  | C16 | 1uF | C-1uF-0805:1uF | Capacitor_SMD:C_0805_2012Metric | http://www.samsungsem.com/kr/support/product-search/mlcc/CL21B105KPFNNNE.jsp |  |  |  |  | YAGEO |  | CC0805KKX7R7BB105 |  | CL21B105KPFNNNE | Digi-Key |  | 311-1365-1-ND
 |  | C17 | 2.2uF | C-2.2uF-0805:2.2uF | Capacitor_SMD:C_0805_2012Metric | http://www.samsungsem.com/kr/support/product-search/mlcc/CL21B225KPFNNNE.jsp |  |  |  |  | Samsung Electro-Mechanics |  | CL21B225KPFNNNE |  |  | Digi-Key |  | 1276-1188-1-ND
 |  | C18 | 1uF | C-1uF-0805:1uF | Capacitor_SMD:C_0805_2012Metric | http://www.samsungsem.com/kr/support/product-search/mlcc/CL21B105KPFNNNE.jsp |  |  |  |  | YAGEO |  | CC0805KKX7R7BB105 |  | CL21B105KPFNNNE | Digi-Key |  | 311-1365-1-ND
 |  | C19 | 220uF | C-220uF-2917:220uF | C-2917-7343-Metric:C-2917-7343-Metric | https://suntsu.com/wp-content/uploads/2020/10/NEMCO_PCT-Series_10.19.2020.pdf |  |  |  |  | Nemco |  | PCT220/10HK |  |  | Digi-Key |  | 2388-PCT220/10HK-ND
 |  | C20 | 100nF | C-100nF-0805:100nF | Capacitor_SMD:C_0805_2012Metric | https://datasheets.avx.com/X7RDielectric.pdf |  |  |  |  | AVX Corporation |  |  |  | 08055C104KAT2A | Digi-Key |  | 478-1395-1-ND
 |  | C21 | 33nF | C-33nF-0805:33nF | Capacitor_SMD:C_0805_2012Metric | https://www.we-online.de/katalog/datasheet/885012207095.pdf |  |  |  |  | Würth Elektronik |  | 885012207095 |  |  | Digi-Key |  | 732-8077-1-ND
 |  | C22 | 1uF | C-1uF-0805:1uF | Capacitor_SMD:C_0805_2012Metric | http://www.samsungsem.com/kr/support/product-search/mlcc/CL21B105KPFNNNE.jsp |  |  |  |  | YAGEO |  | CC0805KKX7R7BB105 |  | CL21B105KPFNNNE | Digi-Key |  | 311-1365-1-ND
 |  | D1 | ORANGE-CLEAR | LED-ORANGE-CLEAR-0805:ORANGE-CLEAR | LED_SMD:LED_0805_2012Metric | https://www.sunledusa.com/products/spec/XZMOK54W-1.pdf |  |  |  |  | SunLED |  | XZMOK54W-1 |  |  | Digi-Key |  | 1497-1188-1-ND
 |  | D2 | GREEN-CLEAR | LED-GREEN-CLEAR-0805:GREEN-CLEAR | LED_SMD:LED_0805_2012Metric | https://www.we-online.de/katalog/datasheet/150080VS75000.pdf |  |  |  |  | Würth Elektronik |  | 150080VS75000 |  |  | Digi-Key |  | 732-4983-1-ND
 |  | D3 | CPDT6-5V4-HF | CPDT6-5V4-HF:CPDT6-5V4-HF | Package_TO_SOT_SMD:SOT-23-6_Handsoldering | https://www.mouser.com/datasheet/2/80/CPDT6-5V4-HF_RevC831377-1481299.pdf |  |  |  |  | Comchip Technology |  |  |  | CPDT6-5V4-HF | Digi-Key | Mouser | 641-1086-1-ND | 750-CPDT6-5V4-HF
 |  | D4 | RED-CLEAR | LED-RED-CLEAR-0805:RED-CLEAR | LED_SMD:LED_0805_2012Metric | https://www.we-online.de/katalog/datasheet/150080SS75000.pdf |  |  |  |  | Würth Elektronik |  | 150080SS75000 |  |  | Digi-Key |  | 732-4985-1-ND
 |  | D5 | GREEN-CLEAR | LED-GREEN-CLEAR-0805:GREEN-CLEAR | LED_SMD:LED_0805_2012Metric | https://www.we-online.de/katalog/datasheet/150080VS75000.pdf |  |  |  |  | Würth Elektronik |  | 150080VS75000 |  |  | Digi-Key |  | 732-4983-1-ND
 |  | D8 | YELLOW-CLEAR | LED-YELLOW-CLEAR-0805:YELLOW-CLEAR | LED_SMD:LED_0805_2012Metric | https://media.digikey.com/PDF/Data%20Sheets/Everlight%20PDFs/qtlp630c-2.pdf |  |  |  |  | Everlight Electronics Co Ltd |  | QTLP630C3TR |  |  | Digi-Key |  | 1080-1410-1-ND
 |  | FB1 | 350m | FB-350m-300mA-0805:350m | Resistor_SMD:R_0805_2012Metric | https://www.fair-rite.com/wp-content/themes/fair-rite/print_product.php?pid=19103 |  |  |  |  | Fair-Rite Products Corp. |  |  |  | 2508056017Y0 | Digi-Key |  | 1934-1468-1-ND
 |  | FB2 | 350m | FB-350m-300mA-0805:350m | Resistor_SMD:R_0805_2012Metric | https://www.fair-rite.com/wp-content/themes/fair-rite/print_product.php?pid=19103 |  |  |  |  | Fair-Rite Products Corp. |  |  |  | 2508056017Y0 | Digi-Key |  | 1934-1468-1-ND
 |  | J1 | UJ31-CH-G2-SMT-TR | UJ31-CH-G2-SMT-TR:UJ31-CH-G2-SMT-TR | UJ31CHG2SMTTR:UJ31CHG2SMTTR | https://www.arrow.com/en/products/uj31-ch-g2-smt-tr/cui-devices | USB Connectors USB jack 3.1 C type 24pin Horz SMT |  | 4.66 |  |  |  |  | CUI Devices | UJ31-CH-G2-SMT-TR | Digi-Key | Mouser | 102-4483-1-ND | 490-UJ31-CH-G2SMT-TR
 |  | J2 | BAT-HLD-001-THM | BAT-HLD-001-THM:BAT-HLD-001-THM | BAT-HLD-001-THM:BATHLD001THM | http://www.mouser.com/datasheet/2/238/BAT-HLD-001-THM Diagram-1175214.pdf | Coin Cell Battery Holders Bat Hld CR2032/2025 Through-hole Mount |  | 4.2 |  |  |  |  | Linx Technologies | BAT-HLD-001-THM | Digi-Key | Mouser | BAT-HLD-001-THM-ND | 712-BAT-HLD-001-THM
 |  | J3 | Conn_01x02_Male | Connector:Conn_01x02_Male | Connector_PinHeader_2.54mm:PinHeader_1x02_P2.54mm_Vertical | ~
 |  | J4 | U.FL-R-SMT-1_10_ | U.FL-R-SMT-1_10_:U.FL-R-SMT-1_10_ | U.FL-R-SMT-1(10):U.FL-R-SMT-1_10_ | https://www.hirose.com/product/document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 | UFL SMT PCB receptable,DC-6GHz Hirose Straight 50 Surface Mount UFL Connector, Receptacle, Solder Termination Coaxial |  |  |  |  | Hirose | U.FL-R-SMT-1(10) |  |  | Digi-Key | Mouser | H11891CT-ND | 798-U.FL-R-SMT-110
 |  | J5 | BH-18650-PC | BH-18650-PC:BH-18650-PC | Battery:BatteryHolder_MPD_BH-18650-PC2 | http://www.memoryprotectiondevices.com/datasheets/BH-18650-PC-datasheet.pdf | BATTERY HOLDER 18650 PC PIN |  | 21.31 |  |  |  |  | MPD (Memory Protection Devices) | BH-18650-PC | Digi-Key |  | BH-18650-PC-ND
 |  | J7 | Conn_01x02_Male | Connector:Conn_01x02_Male | Connector_PinHeader_2.54mm:PinHeader_1x02_P2.54mm_Vertical | ~
 |  | J8 | Conn_01x03_Male | Connector:Conn_01x03_Male | Connector_PinHeader_2.54mm:PinHeader_1x03_P2.54mm_Vertical | ~
 |  | J9 | U.FL-R-SMT-1_10_ | U.FL-R-SMT-1_10_:U.FL-R-SMT-1_10_ | U.FL-R-SMT-1(10):U.FL-R-SMT-1_10_ | https://www.hirose.com/product/document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 | UFL SMT PCB receptable,DC-6GHz Hirose Straight 50 Surface Mount UFL Connector, Receptacle, Solder Termination Coaxial |  |  |  |  | Hirose | U.FL-R-SMT-1(10) |  |  | Digi-Key | Mouser | H11891CT-ND | 798-U.FL-R-SMT-110
 |  | J10 | Conn_01x06_Male | Connector:Conn_01x06_Male | Connector_PinHeader_2.54mm:PinHeader_1x06_P2.54mm_Vertical | ~
 |  | J11 | TERM-BLK-2P | TERMINAL-BLOCK-2P-508:TERM-BLK-2P | TerminalBlock:TerminalBlock_bornier-2_P5.08mm | http://www.on-shore.com/wp-content/uploads/OSTTCXX2162.pdf |  | OSTTC022162 |  |  | On Shore Technology Inc. |  |  |  |  | Digi-Key |  | ED2609-ND
 |  | J14 | Conn_01x09_Male | Connector:Conn_01x09_Male | Connector_PinHeader_2.54mm:PinHeader_1x09_P2.54mm_Vertical | ~
 |  | L1 | 104CDMCCDS-2R2MC | L-2.2uH-11.5x10.3x4:104CDMCCDS-2R2MC | L-11.5x10.3x4:L-11.5x10.3x4 | https://products.sumida.com/products/pdf/104CDMCCDS.pdf | FIXED IND 2.2UH 15A 7 MOHM SMD |  | 4 |  |  |  |  | Sumida | 104CDMCCDS-2R2MC | Digi-Key |  | 308-2499-1-ND
 |  | L2 | 5.5uH | L-5.5uH-10.5x10.2x5:5.5uH | L-10.5x10.2x5:L-10.5x10.2x5 | http://katalog.we-online.de/pbs/datasheet/744325550.pdf | Inductor SMD high current WE-HCI 5.5uH Wurth WE-HCI Series Shielded Wire-wound SMD Inductor with a WE-Superflux Core, 5.5 ??H ??20% 12A Idc |  | 5 |  | Wurth Elektronik |  | 744325550 |  |  | Digi-Key | Mouser | 732-1171-1-ND | 710-744325550
 |  | Q1 | MMBT2222LT1G | NPN-30V-600mA:MMBT2222LT1G | Package_TO_SOT_SMD:SOT-23 | https://www.onsemi.com/pdf/datasheet/mmbt2222lt1-d.pdf |  |  |  |  | ON Semiconductor |  |  |  | MMBT2222LT1G | Digi-Key |  | MMBT2222LT1GOSCT-ND
 |  | Q2 | MMBT2222LT1G | NPN-30V-600mA:MMBT2222LT1G | Package_TO_SOT_SMD:SOT-23 | https://www.onsemi.com/pdf/datasheet/mmbt2222lt1-d.pdf |  |  |  |  | ON Semiconductor |  |  |  | MMBT2222LT1G | Digi-Key |  | MMBT2222LT1GOSCT-ND
 |  | Q3 | MMBT2222LT1G | NPN-30V-600mA:MMBT2222LT1G | Package_TO_SOT_SMD:SOT-23 | https://www.onsemi.com/pdf/datasheet/mmbt2222lt1-d.pdf |  |  |  |  | ON Semiconductor |  |  |  | MMBT2222LT1G | Digi-Key |  | MMBT2222LT1GOSCT-ND
 |  | R1 | 1M | R-1M-0805:1M | Resistor_SMD:R_0805_2012Metric | https://www.seielect.com/catalog/sei-rmcf_rmcp.pdf |  |  |  |  | Stackpole Electronics Inc |  | RMCF0805FT1M00 |  |  | Digi-Key |  | RMCF0805FT1M00CT-ND
 |  | R2 | 90.9K | R-90.9K-0805:90.9K | Resistor_SMD:R_0805_2012Metric | https://www.seielect.com/catalog/sei-rmcf_rmcp.pdf |  |  |  |  | Stackpole Electronics Inc |  | RMCF0805FT90K9 |  |  | Digi-Key |  | RMCF0805FT90K9CT-ND
 |  | R3 | 620 | R-620-0805:620 | Resistor_SMD:R_0805_2012Metric | https://www.yageo.com/upload/media/product/productsearch/datasheet/rchip/PYu-RC_Group_51_RoHS_L_11.pdf |  |  |  |  | Yageo |  |  |  | RC0805JR-07620RL | Digi-Key |  | 311-620ARCT-ND
 |  | R4 | 5.1k | R-5.1k-0805:5.1k | Resistor_SMD:R_0805_2012Metric | https://www.seielect.com/catalog/sei-rmcf_rmcp.pdf |  |  |  |  | Stackpole Electronics Inc |  |  |  | RMCF0805FT5K10 | Digi-Key |  | RMCF0805FT5K10CT-ND
 |  | R5 | 620 | R-620-0805:620 | Resistor_SMD:R_0805_2012Metric | https://www.yageo.com/upload/media/product/productsearch/datasheet/rchip/PYu-RC_Group_51_RoHS_L_11.pdf |  |  |  |  | Yageo |  |  |  | RC0805JR-07620RL | Digi-Key |  | 311-620ARCT-ND
 |  | R6 | 5.1k | R-5.1k-0805:5.1k | Resistor_SMD:R_0805_2012Metric | https://www.seielect.com/catalog/sei-rmcf_rmcp.pdf |  |  |  |  | Stackpole Electronics Inc |  |  |  | RMCF0805FT5K10 | Digi-Key |  | RMCF0805FT5K10CT-ND
 |  | R7 | 49.9K | R-49.9K-0805:49.9K | Resistor_SMD:R_0805_2012Metric | https://www.seielect.com/catalog/sei-rmcf_rmcp.pdf |  |  |  |  | Stackpole Electronics Inc |  | RMCF0805FT49K9 |  |  | Digi-Key |  | RMCF0805FT49K9CT-ND
 |  | R8 | 825K | R-825K-0805:825K | Resistor_SMD:R_0805_2012Metric | https://industrial.panasonic.com/cdbs/www-data/pdf/RDM0000/AOA0000C307.pdf |  |  |  |  | Panasonic Electronic Components |  | ERA-6AED8253V |  |  | Digi-Key |  | P825KBNCT-ND
 |  | R9 | 182K | R-182K-0805:182K | Resistor_SMD:R_0805_2012Metric | https://www.koaspeer.com/pdfs/RK73H.pdf |  |  |  |  | KOA Speer Electronics, Inc. |  | RK73H2ATTD1823F |  |  | Digi-Key |  | 2019-RK73H2ATTD1823FCT-ND
 |  | R10 | 1.2K | R-1.2K-0805:1.2K | Resistor_SMD:R_0805_2012Metric_Pad1.20x1.40mm_HandSolder | https://www.yageo.com/upload/media/product/productsearch/datasheet/rchip/PYu-RC_Group_51_RoHS_L_11.pdf |  |  |  |  | YAGEO |  | RC0805JR-071K2L |  |  | Digi-Key |  | 311-1.2KARCT-ND
 |  | R11 | 6.49K | R-6.49K-0805:6.49K | Resistor_SMD:R_0805_2012Metric | https://industrial.panasonic.com/cdbs/www-data/pdf/RDA0000/AOA0000C304.pdf |  |  |  |  | Panasonic Electronic Components |  | ERJ-6ENF6491V |  |  | Digi-Key |  | P6.49KCCT-ND
 |  | R12 | 27 | R-27-0805:27 | Resistor_SMD:R_0805_2012Metric | https://www.seielect.com/catalog/sei-rmcf_rmcp.pdf |  |  |  |  | Stackpole Electronics Inc |  |  |  | RMCF0805FT27R0 | Digi-Key |  | 738-RMCF0805FT27R0CT-ND
 |  | R13 | 27 | R-27-0805:27 | Resistor_SMD:R_0805_2012Metric | https://www.seielect.com/catalog/sei-rmcf_rmcp.pdf |  |  |  |  | Stackpole Electronics Inc |  |  |  | RMCF0805FT27R0 | Digi-Key |  | 738-RMCF0805FT27R0CT-ND
 |  | R14 | 5.1k | R-5.1k-0805:5.1k | Resistor_SMD:R_0805_2012Metric | https://www.seielect.com/catalog/sei-rmcf_rmcp.pdf |  |  |  |  | Stackpole Electronics Inc |  |  |  | RMCF0805FT5K10 | Digi-Key |  | RMCF0805FT5K10CT-ND
 |  | R15 | 10K | R-10K-0805:10K | Resistor_SMD:R_0805_2012Metric | https://www.vishay.com/docs/28773/crcwce3.pdf |  |  |  |  | Vishay Dale |  |  |  | CRCW080510K0FKEAC | Digi-Key |  | 541-3976-1-ND
 |  | R16 | 10K | R-10K-0805:10K | Resistor_SMD:R_0805_2012Metric | https://www.vishay.com/docs/28773/crcwce3.pdf |  |  |  |  | Vishay Dale |  |  |  | CRCW080510K0FKEAC | Digi-Key |  | 541-3976-1-ND
 |  | R17 | 1K | R-1K-0805:1K | Resistor_SMD:R_0805_2012Metric | https://www.seielect.com/catalog/sei-rmcf_rmcp.pdf |  |  |  |  | Stackpole Electronics Inc |  |  |  | RMCF0805FT1K00 | Digi-Key |  | RMCF0805FT1K00CT-ND
 |  | R18 | 10K | R-10K-0805:10K | Resistor_SMD:R_0805_2012Metric | https://www.vishay.com/docs/28773/crcwce3.pdf |  |  |  |  | Vishay Dale |  |  |  | CRCW080510K0FKEAC | Digi-Key |  | 541-3976-1-ND
 |  | R19 | 1.8M | R-1.8M-0805:1.8M | Resistor_SMD:R_0805_2012Metric | https://industrial.panasonic.com/cdbs/www-data/pdf/RDA0000/AOA0000C304.pdf |  |  |  |  | Panasonic Electronic Components |  | ERJ-6ENF1804V |  |  | Digi-Key |  | P1.80MCCT-ND
 |  | R20 | 390K | R-390K-0805:390K | Resistor_SMD:R_0805_2012Metric | https://www.yageo.com/upload/media/product/productsearch/datasheet/rchip/PYu-RC_Group_51_RoHS_L_11.pdf |  |  |  |  | YAGEO |  | RC0805FR-07390KL |  |  | Digi-Key |  | 311-390KCRCT-ND
 |  | R21 | 806K | R-806K-0805:806K | Capacitor_SMD:C_0805_2012Metric | https://industrial.panasonic.com/cdbs/www-data/pdf/RDA0000/AOA0000C304.pdf |  |  |  |  | Panasonic Electronic Components |  | ERJ-6ENF8063V |  |  | Digi-Key |  | P806KCCT-ND
 |  | R22 | 2M | R-2M-0805:2M | Capacitor_SMD:C_0805_2012Metric | https://www.vishay.com/docs/28773/crcwce3.pdf |  |  |  |  | Vishay Dale |  | CRCW08052M00FKECC |  |  | Digi-Key |  | 541-4129-1-ND
 |  | R23 | 10K | R-10K-0805:10K | Resistor_SMD:R_0805_2012Metric | https://www.vishay.com/docs/28773/crcwce3.pdf |  |  |  |  | Vishay Dale |  |  |  | CRCW080510K0FKEAC | Digi-Key |  | 541-3976-1-ND
 |  | R24 | 10K | R-10K-0805:10K | Resistor_SMD:R_0805_2012Metric | https://www.vishay.com/docs/28773/crcwce3.pdf |  |  |  |  | Vishay Dale |  |  |  | CRCW080510K0FKEAC | Digi-Key |  | 541-3976-1-ND
 |  | R25 | 10K | R-10K-0805:10K | Resistor_SMD:R_0805_2012Metric | https://www.vishay.com/docs/28773/crcwce3.pdf |  |  |  |  | Vishay Dale |  |  |  | CRCW080510K0FKEAC | Digi-Key |  | 541-3976-1-ND
 |  | R26 | 1M | R-1M-0805:1M | Resistor_SMD:R_0805_2012Metric | https://www.seielect.com/catalog/sei-rmcf_rmcp.pdf |  |  |  |  | Stackpole Electronics Inc |  | RMCF0805FT1M00 |  |  | Digi-Key |  | RMCF0805FT1M00CT-ND
 |  | R27 | 180K | R-180K-0805:180K | Resistor_SMD:R_0805_2012Metric | https://www.susumu.co.jp/common/pdf/n_catalog_partition05_en.pdf |  |  |  |  | Susumu |  | RR1220P-184-D |  |  | Digi-Key |  | RR12P180KDCT-ND
 |  | R28 | 10K | R-10K-0805:10K | Resistor_SMD:R_0805_2012Metric | https://www.vishay.com/docs/28773/crcwce3.pdf |  |  |  |  | Vishay Dale |  |  |  | CRCW080510K0FKEAC | Digi-Key |  | 541-3976-1-ND
 |  | R29 | 10K | R-10K-0805:10K | Resistor_SMD:R_0805_2012Metric | https://www.vishay.com/docs/28773/crcwce3.pdf |  |  |  |  | Vishay Dale |  |  |  | CRCW080510K0FKEAC | Digi-Key |  | 541-3976-1-ND
 |  | R30 | 620 | R-620-0805:620 | Resistor_SMD:R_0805_2012Metric | https://www.yageo.com/upload/media/product/productsearch/datasheet/rchip/PYu-RC_Group_51_RoHS_L_11.pdf |  |  |  |  | Yageo |  |  |  | RC0805JR-07620RL | Digi-Key |  | 311-620ARCT-ND
 |  | R31 | 620 | R-620-0805:620 | Resistor_SMD:R_0805_2012Metric | https://www.yageo.com/upload/media/product/productsearch/datasheet/rchip/PYu-RC_Group_51_RoHS_L_11.pdf |  |  |  |  | Yageo |  |  |  | RC0805JR-07620RL | Digi-Key |  | 311-620ARCT-ND
 |  | R32 | 0 | R-0-0805:0 | Resistor_SMD:R_0805_2012Metric | https://www.yageo.com/upload/media/product/productsearch/datasheet/rchip/PYu-RC_Group_51_RoHS_L_11.pdf |  |  |  |  | Yageo |  | RC0805JR-070RL |  |  | Digi-Key |  | 311-0.0ARCT-ND
 |  | R33 | 0 | R-0-0805:0 | Resistor_SMD:R_0805_2012Metric | https://www.yageo.com/upload/media/product/productsearch/datasheet/rchip/PYu-RC_Group_51_RoHS_L_11.pdf |  |  |  |  | Yageo |  | RC0805JR-070RL |  |  | Digi-Key |  | 311-0.0ARCT-ND
 |  | R34 | 620 | R-620-0805:620 | Resistor_SMD:R_0805_2012Metric | https://www.yageo.com/upload/media/product/productsearch/datasheet/rchip/PYu-RC_Group_51_RoHS_L_11.pdf |  |  |  |  | Yageo |  |  |  | RC0805JR-07620RL | Digi-Key |  | 311-620ARCT-ND
 |  | R36 | 10K | R-10K-0805:10K | Resistor_SMD:R_0805_2012Metric | https://www.vishay.com/docs/28773/crcwce3.pdf |  |  |  |  | Vishay Dale |  |  |  | CRCW080510K0FKEAC | Digi-Key |  | 541-3976-1-ND
 |  | R37 | 10K | R-10K-0805:10K | Resistor_SMD:R_0805_2012Metric | https://www.vishay.com/docs/28773/crcwce3.pdf |  |  |  |  | Vishay Dale |  |  |  | CRCW080510K0FKEAC | Digi-Key |  | 541-3976-1-ND
 |  | U1 | ATGM332D-5N31 | ATGM332D-5N31:ATGM332D-5N31 | ATGM332D-5N31:ATGM332D5N31 | https://datasheet.lcsc.com/szlcsc/ZHONGKEWEI-ATGM332D-5N31_C128659.pdf | Communication Modules/GNSS Modules 12.2x16x2.4mm |  | 2.6 | C128659 |  |  |  | ZHONGKEWEI | ATGM332D-5N31
 |  | U2 | LTC3113EFE#TRPBF | LTC3113EFE#TRPBF:LTC3113EFE#TRPBF | Package_SO:HTSSOP-20-1EP_4.4x6.5mm_P0.65mm_EP3.4x6.5mm_Mask2.75x3.43mm_ThermalVias_HandSolder | https://www.analog.com/media/en/technical-documentation/data-sheets/3113f.pdf |  |  |  |  | Analog Devices Inc. |  | LTC3113EFE#TRPBF |  |  | Digi-Key |  | LTC3113EFE#TRPBFCT-ND
 |  | U3 | TP4056 | TP4056:TP4056 | ESOP-8:ESOP-8 |  |  |  |  | C382139
 |  | U4 | ESP32-WROOM-32D | ESP32-WROOM-32D:ESP32-WROOM-32D | ESP32-WROOM-32D:ESP32-WROOM-32D | https://www.mouser.com/datasheet/2/891/esp32-wroom-32d_esp32-wroom-32u_datasheet_en-1365844.pdf | WiFi Modules (802.11) SMD Module, ESP32-D0WD, 32Mbits SPI flash, UART mode, PCB antenna |  | 3.1 | C473012 |  |  |  | Espressif Systems | ESP32-WROOM-32D | Digi-Key |  | 1965-ESP32-WROOM-32D(4MB)CT-ND
 |  | U5 | FT260S-U | FT260S-U:FT260S-U | Package_SO:TSSOP-28_4.4x9.7mm_P0.65mm | https://www.ftdichip.com/Support/Documents/DataSheets/ICs/DS_FT260.pdf | FTDI - FT260S-U - INTERFACE BRIDGE, USB TO I2C/UART, TSSOP |  | 1.2 |  |  |  |  | FTDI Chip | FT260S-U | Digi-Key | Mouser | 768-1282-5-ND | 895-FT260S-U
 |  | U6 | TPS61030PWPR | TPS61030PWPR:TPS61030PWPR | Package_SO:HTSSOP-16-1EP_4.4x5mm_P0.65mm_EP3.4x5mm_Mask3x3mm_ThermalVias | https://www.ti.com/general/docs/suppproductinfo.tsp?distId=10 |  |  |  |  | Texas Instruments |  | TPS61030PWPR |  |  | Digi-Key |  | 296-14416-1-ND
 |  | U7 | RFM95W-915S2 | RFM95W-915S2:RFM95W-915S2 | RF_Module:HOPERF_RFM9XW_SMD | https://www.rfsolutions.co.uk/downloads/1463993415RFM95_96_97_98W.pdf |  |  |  |  |  |  |  |  |  | Digi-Key |  | RFM95W-915S2-ND
 |  | U8 | DS3231M+TRL | DS3231M+TRL:DS3231M+TRL | Package_SO:SOIC-16W_7.5x10.3mm_P1.27mm | https://datasheets.maximintegrated.com/en/ds/DS3231M.pdf |  |  |  |  | Maxim Integrated |  | DS3231M+TRL |  |  | Digi-Key |  | DS3231M+TRLCT-ND
 |  | U10 | LTC2954ITS8-1#TRPBF | LTC2954ITS8-1#TRPBF:LTC2954ITS8-1#TRPBF | Package_TO_SOT_SMD:TSOT-23-8_HandSoldering | https://www.analog.com/media/en/technical-documentation/data-sheets/2954fb.pdf |  |  |  |  | Analog Devices Inc. |  | LTC2954ITS8-1#TRPBF |  |  | Digi-Key |  | LTC2954ITS8-1#TRPBFCT-ND
Collated Components:
Item | Qty | Reference(s) | Value | LibPart | Footprint | Datasheet | Description | Field7 | Height | LCSC | Manufacturer | Manufacturer Name | Manufacturer Part Number | Manufacturer_Name | Manufacturer_Part_Number | Supplier 1 | Supplier 2 | Supplier Part Number 1 | Supplier Part Number 2
1 | 1 | C1 | 47uF | C-47uF-0805:47uF | Capacitor_SMD:C_0805_2012Metric | https://www.yuden.co.jp/productdata/catalog/mlcc06_e.pdf |  |  |  |  | Taiyo Yuden |  | JMK212BBJ476MG-T |  |  | Digi-Key |  | 587-4280-1-ND
2 | 4 | C2, C3, C7, C13 | 10uF | C-10uF-0805:10uF | Capacitor_SMD:C_0805_2012Metric |  |  |  |  |  | Samsung Electro-Mechanics |  | CL21A106KQCLNNC |  |  | Digi-Key |  | 1276-2404-1-ND
3 | 1 | C4 | 12pF | C-12pF-0805:12pF | Capacitor_SMD:C_0805_2012Metric | http://www.seielect.com/Catalog/SEI-CML.PDF |  |  |  |  | Stackpole Electronics Inc |  | CML0805C0G120JT50V |  |  | Digi-Key |  | 738-CML0805C0G120JT50VCT-ND
4 | 1 | C5 | 680pF | C-680pF-0805:680pF | Capacitor_SMD:C_0805_2012Metric | https://www.we-online.de/katalog/datasheet/885012207059.pdf |  |  |  |  | Würth Elektronik |  | 885012207059 |  |  | Digi-Key |  | 732-12279-1-ND
5 | 3 | C6, C10, C12 | 47pF | C-47pF-0805:47pF | Capacitor_SMD:C_0805_2012Metric | https://www.we-online.de/katalog/datasheet/885012007014.pdf |  |  |  |  | Würth Elektronik |  |  |  | 885012007014 | Digi-Key |  | 732-7818-1-ND
6 | 1 | C8 | 100uF | C-100uF-1210:100uF | Capacitor_SMD:C_1210_3225Metric | https://search.murata.co.jp/Ceramy/image/img/A01X/G101/ENG/GRM32EE70J107ME15-01.pdf |  |  |  |  | Murata Electronics |  | GRM32EE70J107ME15L |  |  | Digi-Key |  | 490-10534-1-ND
7 | 3 | C9, C14, C20 | 100nF | C-100nF-0805:100nF | Capacitor_SMD:C_0805_2012Metric | https://datasheets.avx.com/X7RDielectric.pdf |  |  |  |  | AVX Corporation |  |  |  | 08055C104KAT2A | Digi-Key |  | 478-1395-1-ND
8 | 1 | C11 | 4.7uF | C-4.7uF-0805:4.7uF | Capacitor_SMD:C_0805_2012Metric | http://www.samsungsem.com/kr/support/product-search/mlcc/CL21A475KQFNNNE.jsp |  |  |  |  | Samsung Electro-Mechanics |  |  |  | CL21A475KQFNNNE | Digi-Key |  | 1276-1198-1-ND
9 | 4 | C15, C16, C18, C22 | 1uF | C-1uF-0805:1uF | Capacitor_SMD:C_0805_2012Metric | http://www.samsungsem.com/kr/support/product-search/mlcc/CL21B105KPFNNNE.jsp |  |  |  |  | YAGEO |  | CC0805KKX7R7BB105 |  | CL21B105KPFNNNE | Digi-Key |  | 311-1365-1-ND
10 | 1 | C17 | 2.2uF | C-2.2uF-0805:2.2uF | Capacitor_SMD:C_0805_2012Metric | http://www.samsungsem.com/kr/support/product-search/mlcc/CL21B225KPFNNNE.jsp |  |  |  |  | Samsung Electro-Mechanics |  | CL21B225KPFNNNE |  |  | Digi-Key |  | 1276-1188-1-ND
11 | 1 | C19 | 220uF | C-220uF-2917:220uF | C-2917-7343-Metric:C-2917-7343-Metric | https://suntsu.com/wp-content/uploads/2020/10/NEMCO_PCT-Series_10.19.2020.pdf |  |  |  |  | Nemco |  | PCT220/10HK |  |  | Digi-Key |  | 2388-PCT220/10HK-ND
12 | 1 | C21 | 33nF | C-33nF-0805:33nF | Capacitor_SMD:C_0805_2012Metric | https://www.we-online.de/katalog/datasheet/885012207095.pdf |  |  |  |  | Würth Elektronik |  | 885012207095 |  |  | Digi-Key |  | 732-8077-1-ND
13 | 1 | D1 | ORANGE-CLEAR | LED-ORANGE-CLEAR-0805:ORANGE-CLEAR | LED_SMD:LED_0805_2012Metric | https://www.sunledusa.com/products/spec/XZMOK54W-1.pdf |  |  |  |  | SunLED |  | XZMOK54W-1 |  |  | Digi-Key |  | 1497-1188-1-ND
14 | 2 | D2, D5 | GREEN-CLEAR | LED-GREEN-CLEAR-0805:GREEN-CLEAR | LED_SMD:LED_0805_2012Metric | https://www.we-online.de/katalog/datasheet/150080VS75000.pdf |  |  |  |  | Würth Elektronik |  | 150080VS75000 |  |  | Digi-Key |  | 732-4983-1-ND
15 | 1 | D3 | CPDT6-5V4-HF | CPDT6-5V4-HF:CPDT6-5V4-HF | Package_TO_SOT_SMD:SOT-23-6_Handsoldering | https://www.mouser.com/datasheet/2/80/CPDT6-5V4-HF_RevC831377-1481299.pdf |  |  |  |  | Comchip Technology |  |  |  | CPDT6-5V4-HF | Digi-Key | Mouser | 641-1086-1-ND | 750-CPDT6-5V4-HF
16 | 1 | D4 | RED-CLEAR | LED-RED-CLEAR-0805:RED-CLEAR | LED_SMD:LED_0805_2012Metric | https://www.we-online.de/katalog/datasheet/150080SS75000.pdf |  |  |  |  | Würth Elektronik |  | 150080SS75000 |  |  | Digi-Key |  | 732-4985-1-ND
17 | 1 | D8 | YELLOW-CLEAR | LED-YELLOW-CLEAR-0805:YELLOW-CLEAR | LED_SMD:LED_0805_2012Metric | https://media.digikey.com/PDF/Data%20Sheets/Everlight%20PDFs/qtlp630c-2.pdf |  |  |  |  | Everlight Electronics Co Ltd |  | QTLP630C3TR |  |  | Digi-Key |  | 1080-1410-1-ND
18 | 2 | FB1, FB2 | 350m | FB-350m-300mA-0805:350m | Resistor_SMD:R_0805_2012Metric | https://www.fair-rite.com/wp-content/themes/fair-rite/print_product.php?pid=19103 |  |  |  |  | Fair-Rite Products Corp. |  |  |  | 2508056017Y0 | Digi-Key |  | 1934-1468-1-ND
19 | 1 | J1 | UJ31-CH-G2-SMT-TR | UJ31-CH-G2-SMT-TR:UJ31-CH-G2-SMT-TR | UJ31CHG2SMTTR:UJ31CHG2SMTTR | https://www.arrow.com/en/products/uj31-ch-g2-smt-tr/cui-devices | USB Connectors USB jack 3.1 C type 24pin Horz SMT |  | 4.66 |  |  |  |  | CUI Devices | UJ31-CH-G2-SMT-TR | Digi-Key | Mouser | 102-4483-1-ND | 490-UJ31-CH-G2SMT-TR
20 | 1 | J2 | BAT-HLD-001-THM | BAT-HLD-001-THM:BAT-HLD-001-THM | BAT-HLD-001-THM:BATHLD001THM | http://www.mouser.com/datasheet/2/238/BAT-HLD-001-THM Diagram-1175214.pdf | Coin Cell Battery Holders Bat Hld CR2032/2025 Through-hole Mount |  | 4.2 |  |  |  |  | Linx Technologies | BAT-HLD-001-THM | Digi-Key | Mouser | BAT-HLD-001-THM-ND | 712-BAT-HLD-001-THM
21 | 2 | J3, J7 | Conn_01x02_Male | Connector:Conn_01x02_Male | Connector_PinHeader_2.54mm:PinHeader_1x02_P2.54mm_Vertical | ~
22 | 2 | J4, J9 | U.FL-R-SMT-1_10_ | U.FL-R-SMT-1_10_:U.FL-R-SMT-1_10_ | U.FL-R-SMT-1(10):U.FL-R-SMT-1_10_ | https://www.hirose.com/product/document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 | UFL SMT PCB receptable,DC-6GHz Hirose Straight 50 Surface Mount UFL Connector, Receptacle, Solder Termination Coaxial |  |  |  |  | Hirose | U.FL-R-SMT-1(10) |  |  | Digi-Key | Mouser | H11891CT-ND | 798-U.FL-R-SMT-110
23 | 1 | J5 | BH-18650-PC | BH-18650-PC:BH-18650-PC | Battery:BatteryHolder_MPD_BH-18650-PC2 | http://www.memoryprotectiondevices.com/datasheets/BH-18650-PC-datasheet.pdf | BATTERY HOLDER 18650 PC PIN |  | 21.31 |  |  |  |  | MPD (Memory Protection Devices) | BH-18650-PC | Digi-Key |  | BH-18650-PC-ND
24 | 1 | J8 | Conn_01x03_Male | Connector:Conn_01x03_Male | Connector_PinHeader_2.54mm:PinHeader_1x03_P2.54mm_Vertical | ~
25 | 1 | J10 | Conn_01x06_Male | Connector:Conn_01x06_Male | Connector_PinHeader_2.54mm:PinHeader_1x06_P2.54mm_Vertical | ~
26 | 1 | J11 | TERM-BLK-2P | TERMINAL-BLOCK-2P-508:TERM-BLK-2P | TerminalBlock:TerminalBlock_bornier-2_P5.08mm | http://www.on-shore.com/wp-content/uploads/OSTTCXX2162.pdf |  | OSTTC022162 |  |  | On Shore Technology Inc. |  |  |  |  | Digi-Key |  | ED2609-ND
27 | 1 | J14 | Conn_01x09_Male | Connector:Conn_01x09_Male | Connector_PinHeader_2.54mm:PinHeader_1x09_P2.54mm_Vertical | ~
28 | 1 | L1 | 104CDMCCDS-2R2MC | L-2.2uH-11.5x10.3x4:104CDMCCDS-2R2MC | L-11.5x10.3x4:L-11.5x10.3x4 | https://products.sumida.com/products/pdf/104CDMCCDS.pdf | FIXED IND 2.2UH 15A 7 MOHM SMD |  | 4 |  |  |  |  | Sumida | 104CDMCCDS-2R2MC | Digi-Key |  | 308-2499-1-ND
29 | 1 | L2 | 5.5uH | L-5.5uH-10.5x10.2x5:5.5uH | L-10.5x10.2x5:L-10.5x10.2x5 | http://katalog.we-online.de/pbs/datasheet/744325550.pdf | Inductor SMD high current WE-HCI 5.5uH Wurth WE-HCI Series Shielded Wire-wound SMD Inductor with a WE-Superflux Core, 5.5 ??H ??20% 12A Idc |  | 5 |  | Wurth Elektronik |  | 744325550 |  |  | Digi-Key | Mouser | 732-1171-1-ND | 710-744325550
30 | 3 | Q1, Q2, Q3 | MMBT2222LT1G | NPN-30V-600mA:MMBT2222LT1G | Package_TO_SOT_SMD:SOT-23 | https://www.onsemi.com/pdf/datasheet/mmbt2222lt1-d.pdf |  |  |  |  | ON Semiconductor |  |  |  | MMBT2222LT1G | Digi-Key |  | MMBT2222LT1GOSCT-ND
31 | 2 | R1, R26 | 1M | R-1M-0805:1M | Resistor_SMD:R_0805_2012Metric | https://www.seielect.com/catalog/sei-rmcf_rmcp.pdf |  |  |  |  | Stackpole Electronics Inc |  | RMCF0805FT1M00 |  |  | Digi-Key |  | RMCF0805FT1M00CT-ND
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

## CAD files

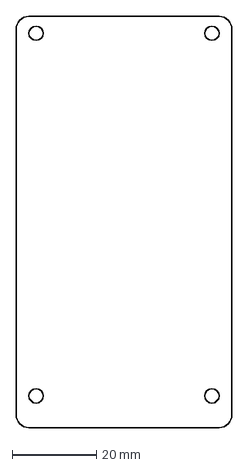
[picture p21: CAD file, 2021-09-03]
board.dxf
51.2 x 97.5 mm

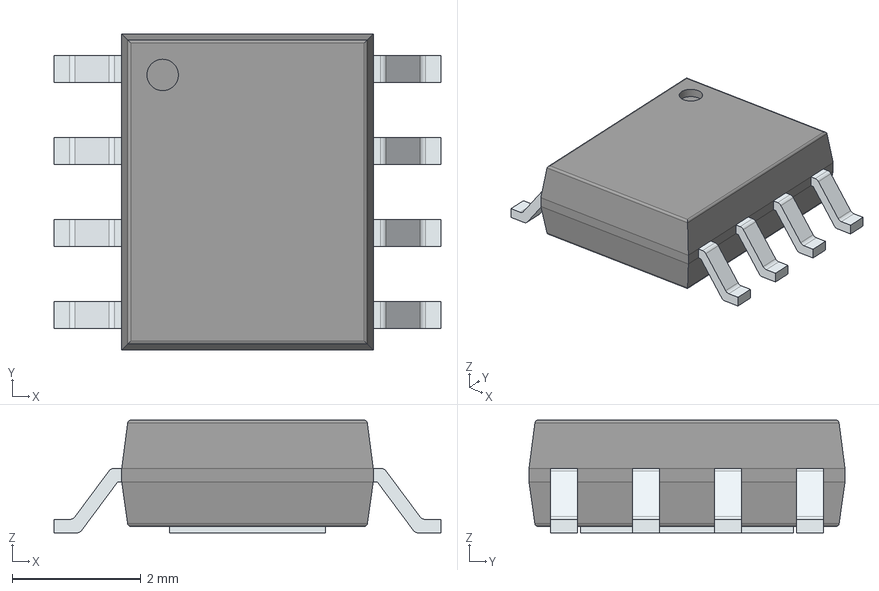
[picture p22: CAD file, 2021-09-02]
buoy-c/3D/TP4056.stp
6.00 x 4.90 x 1.75 mm
PinsArrayLR
ThermalPad

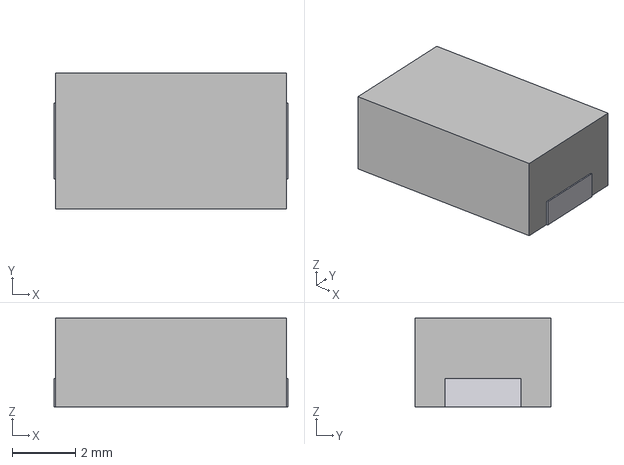
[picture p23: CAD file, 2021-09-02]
buoy-c/3D/ECGSY0G471R.stp
7.40 x 4.30 x 2.80 mm

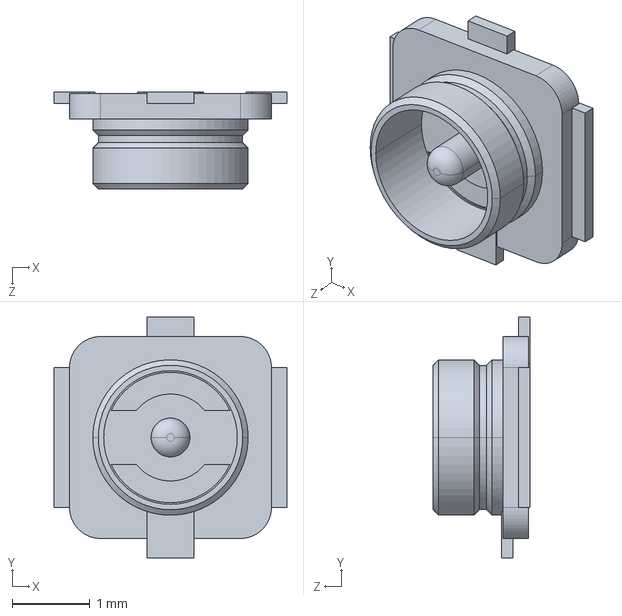
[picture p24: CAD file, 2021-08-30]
buoy-c/3D/U.FL-R-SMT-1_10_.stp
3.00 x 3.10 x 1.25 mm

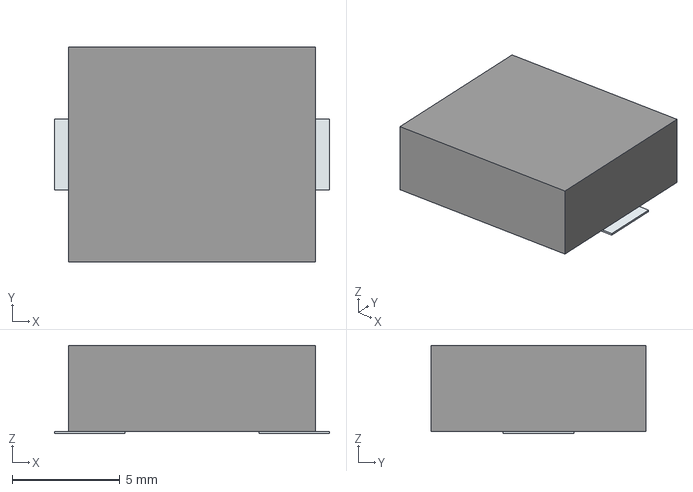
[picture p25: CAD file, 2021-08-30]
buoy-c/3D/L-11.5x10.3x4.stp
12.8 x 10.0 x 4.10 mm
Pins

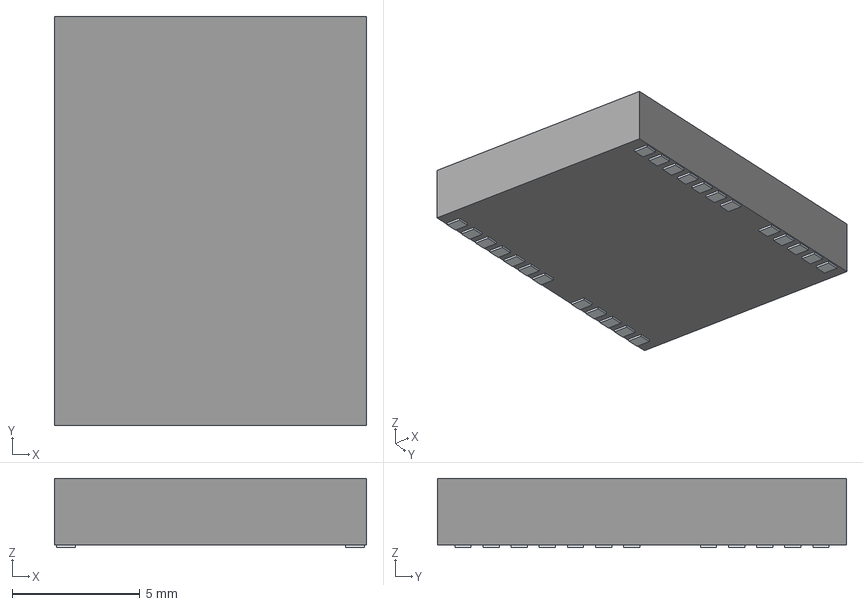
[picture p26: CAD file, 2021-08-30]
buoy-c/3D/ATGM332D-5N31.stp
12.2 x 16.0 x 2.70 mm
Pins

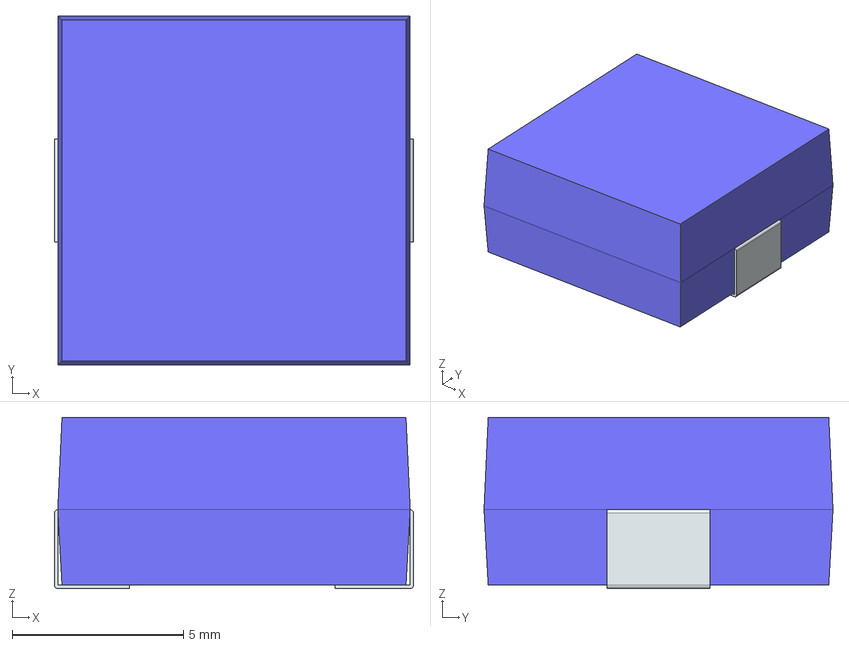
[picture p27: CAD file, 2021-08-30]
buoy-c/3D/L-10.5x10.2x5.stp
10.5 x 10.2 x 5.00 mm
FilletPin1
FilletPin2

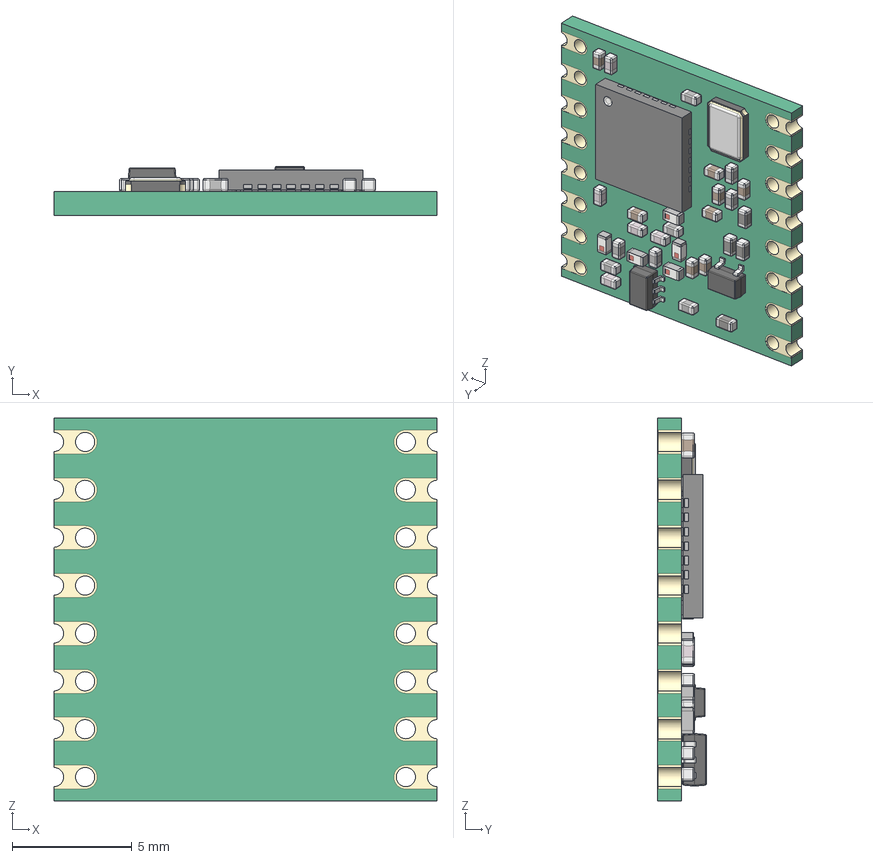
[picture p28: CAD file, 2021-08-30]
buoy-c/3D/RFM95 LoRa v15.step
16.0 x 2.04 x 16.0 mm
QFN 28
SMD Crystal
CAP 0403 x 8
CAP Ceramic 0403 x 8
Res 0403 x 4
CAP ML 0403 x 5
SOT-323
Inductor SMD 0403 x 5
SOT-363

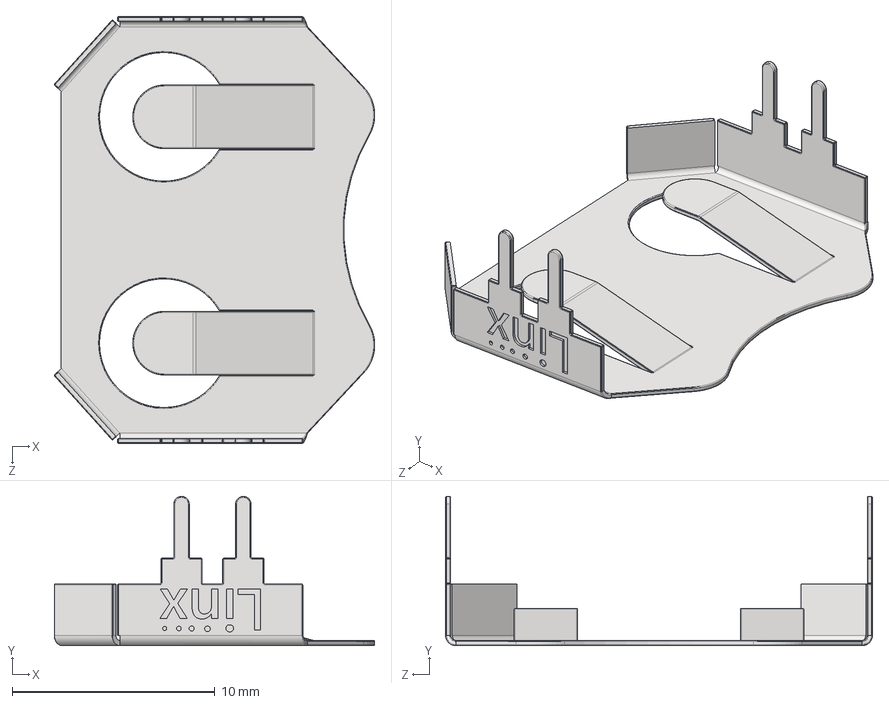
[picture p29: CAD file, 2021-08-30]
buoy-c/3D/BAT-HLD-001-THM.stp
15.8 x 7.37 x 21.1 mm

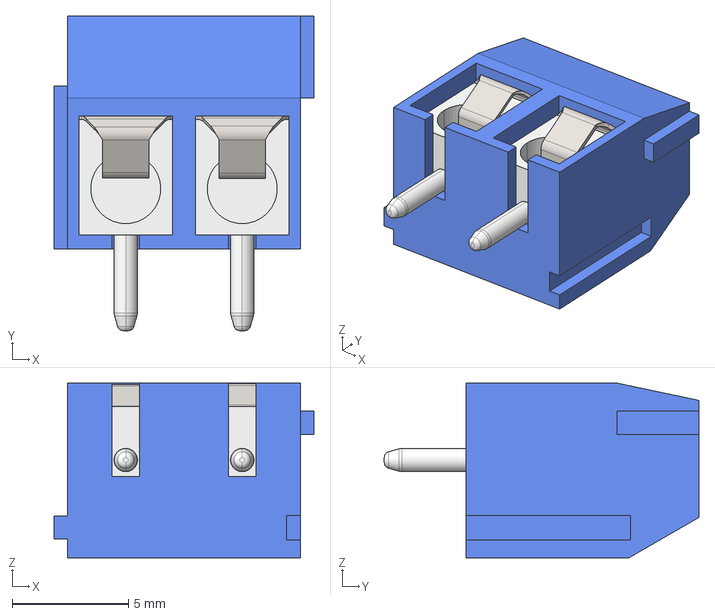
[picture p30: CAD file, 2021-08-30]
buoy-c/3D/TerminalBlock-2.STEP
11.2 x 13.5 x 7.50 mm

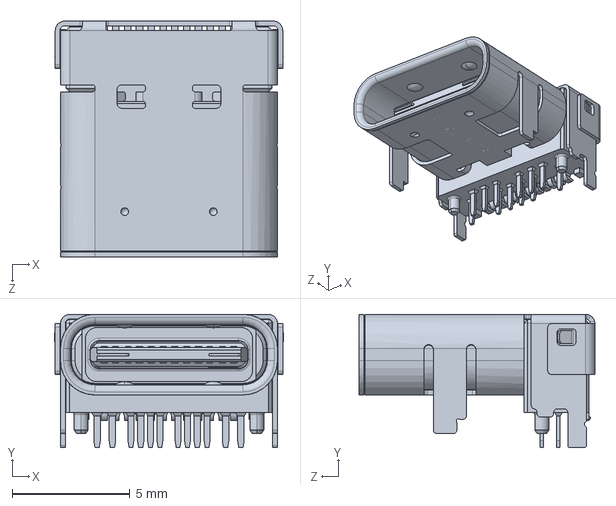
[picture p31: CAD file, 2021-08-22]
buoy-c/3D/UJ31-CH-G2-SMT-TR.stp
9.71 x 5.66 x 10.0 mm

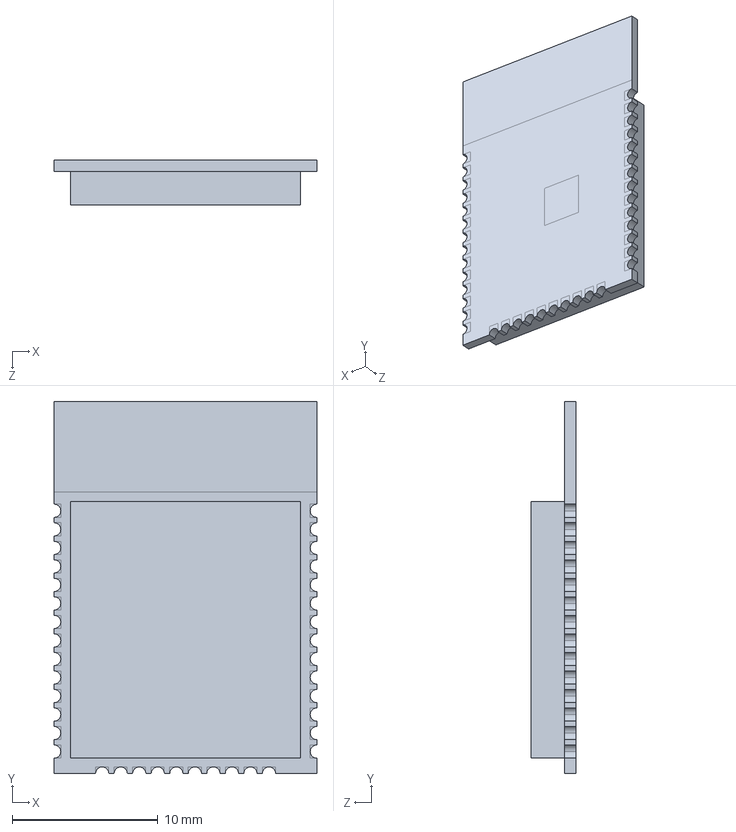
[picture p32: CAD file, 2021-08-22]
buoy-c/3D/ESP32-WROOM-32D.stp
18.0 x 25.5 x 3.10 mm

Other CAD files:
buoy-c/3D/ATGM332D-5N31.stl
buoy-c/3D/L-10.5x10.2x5.stl

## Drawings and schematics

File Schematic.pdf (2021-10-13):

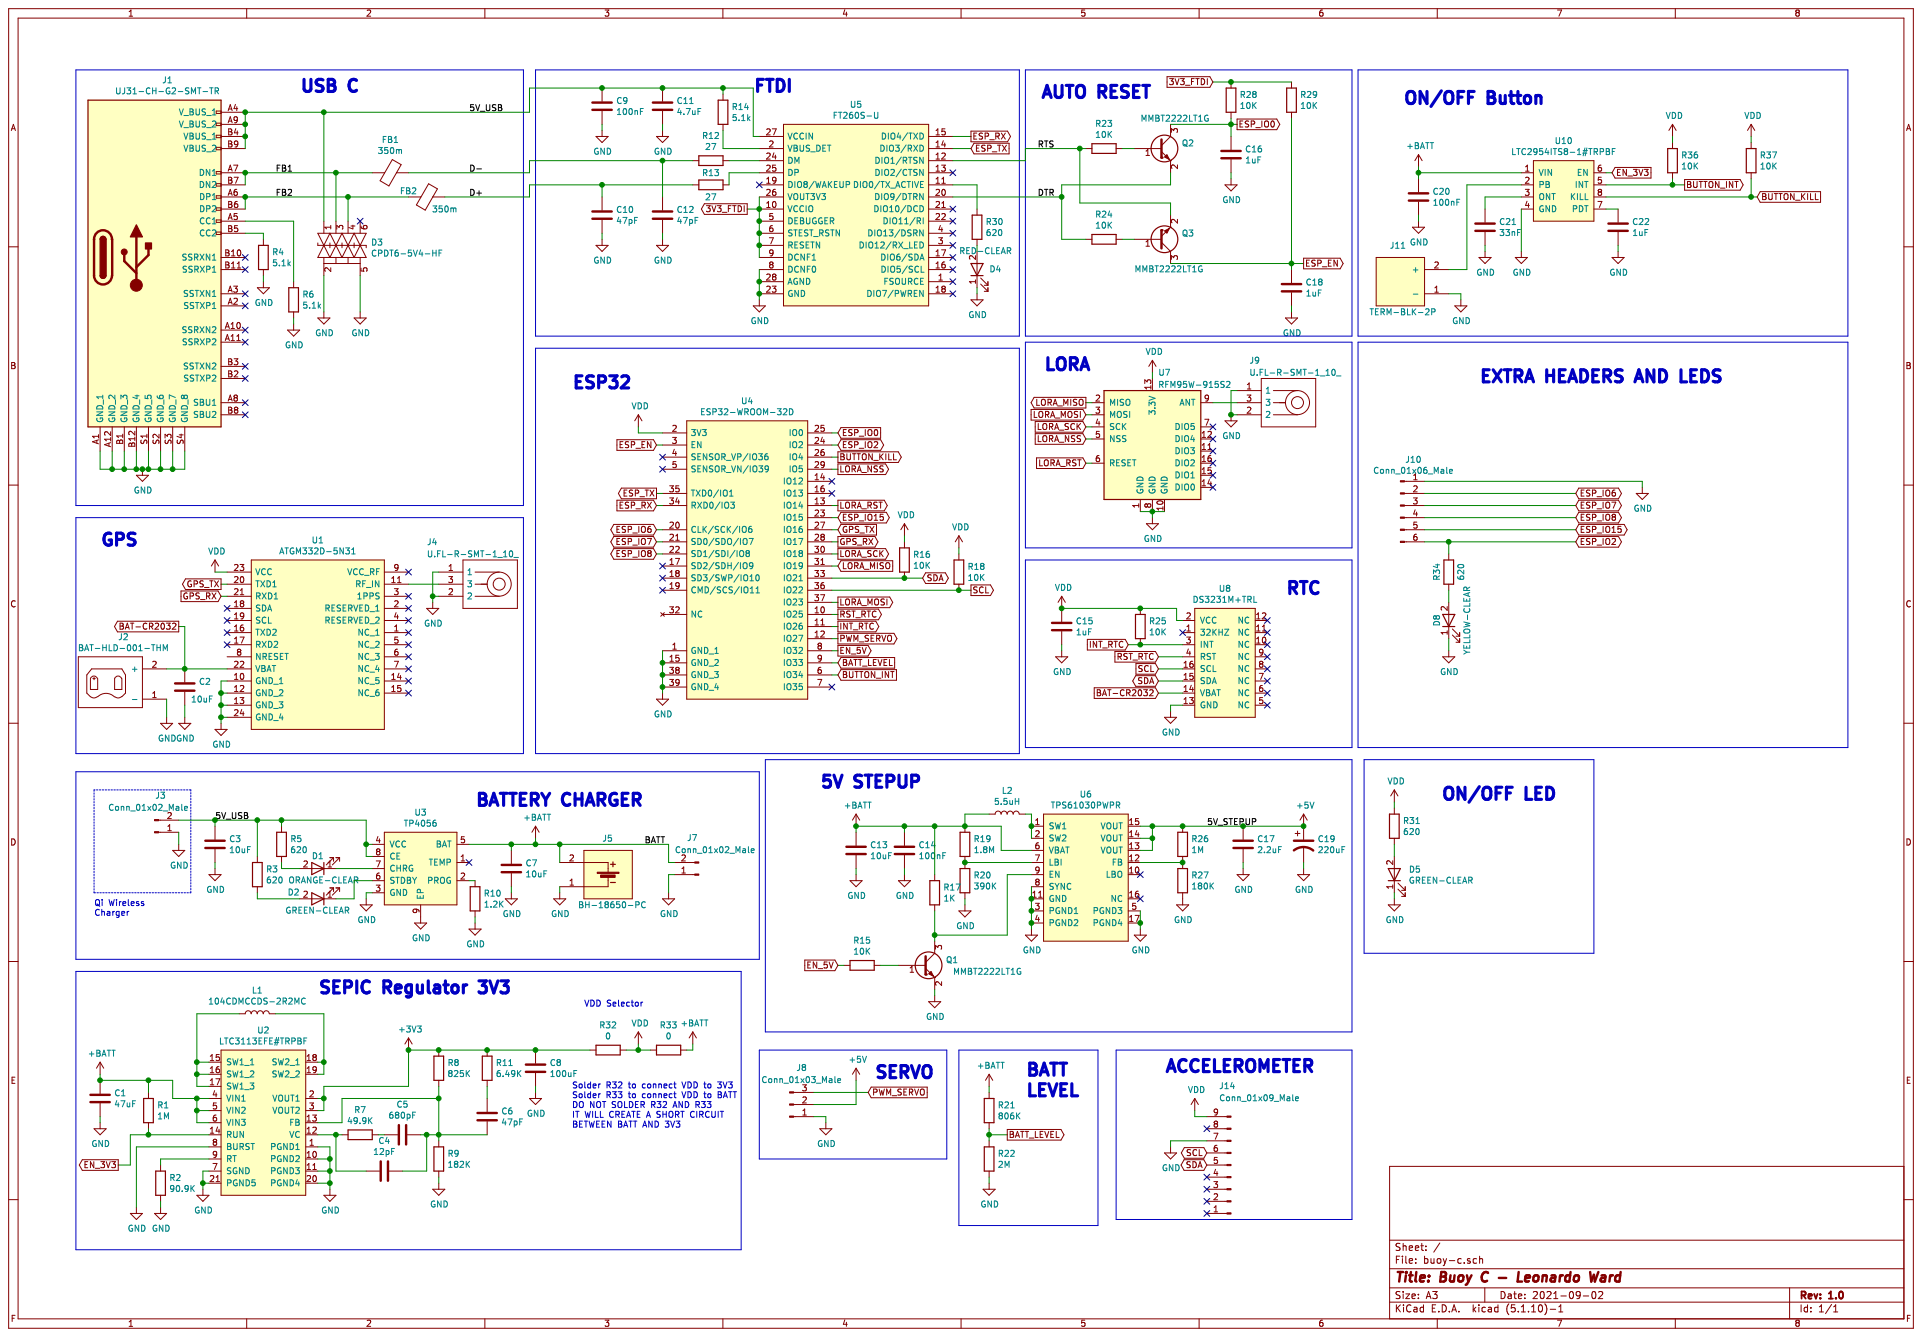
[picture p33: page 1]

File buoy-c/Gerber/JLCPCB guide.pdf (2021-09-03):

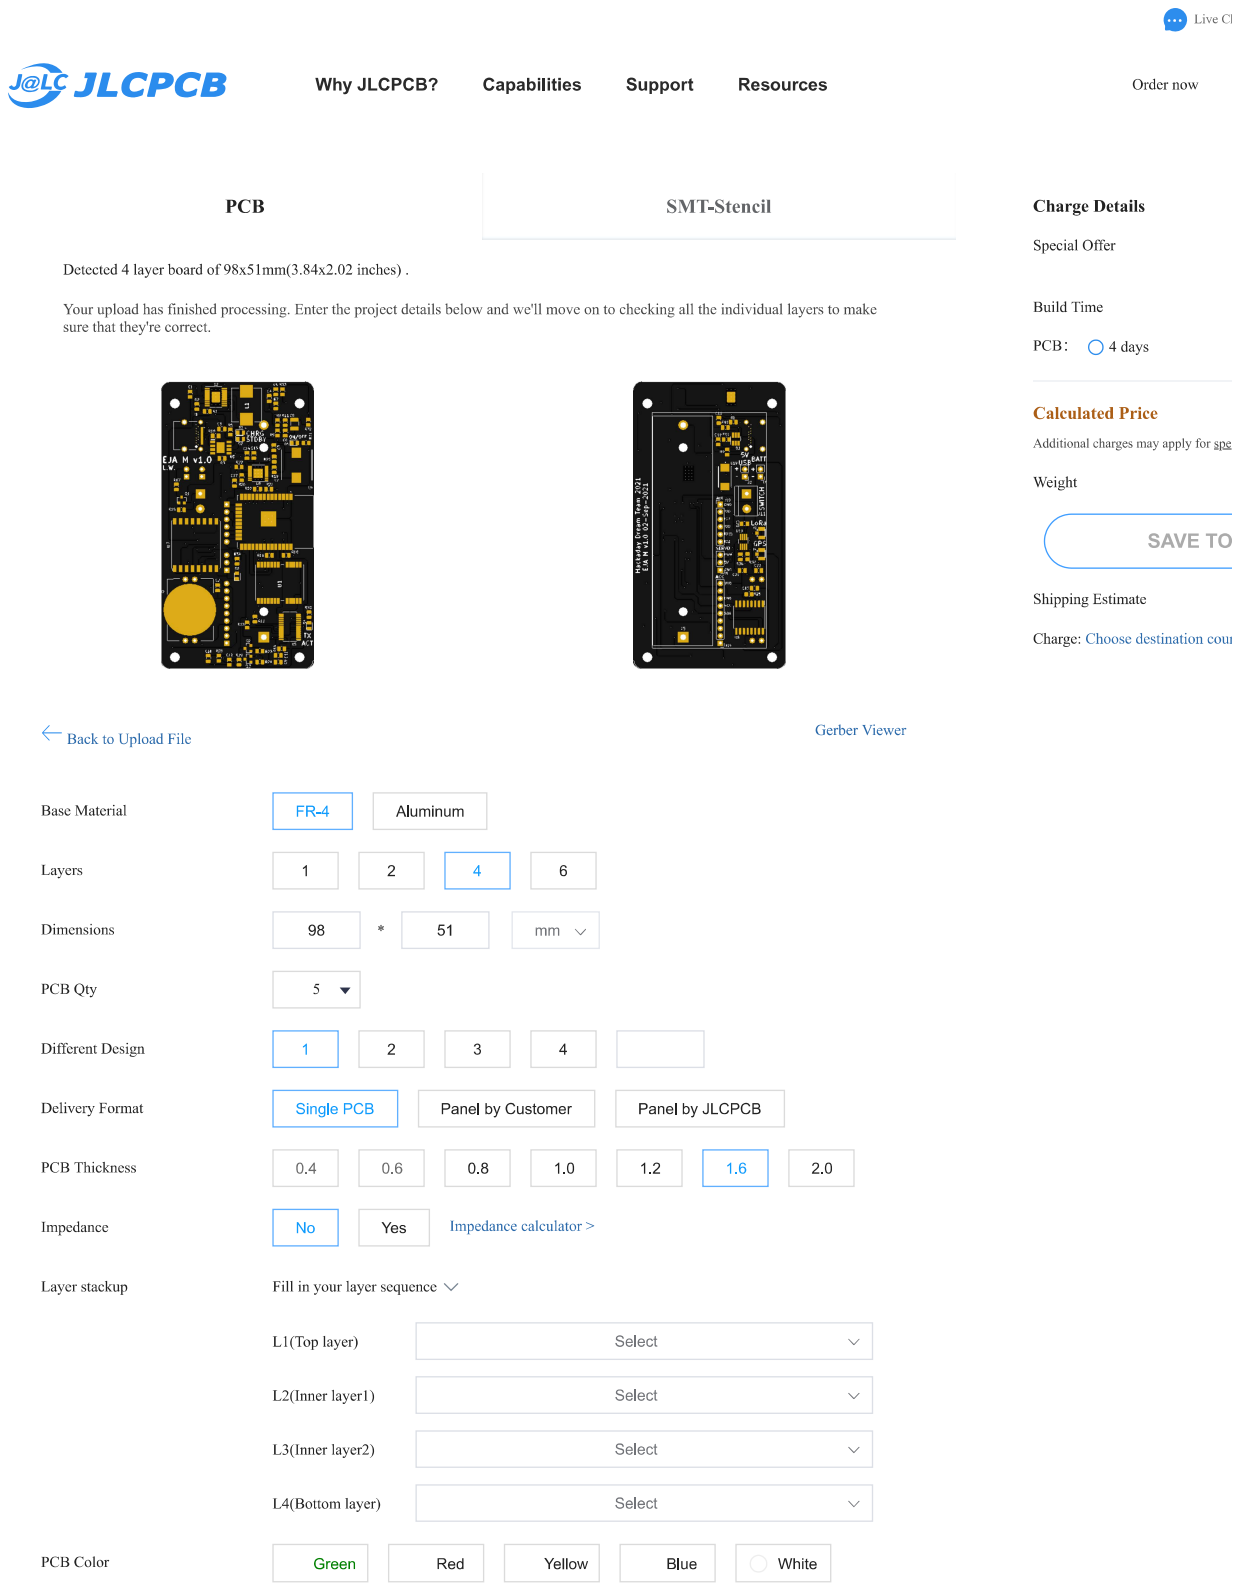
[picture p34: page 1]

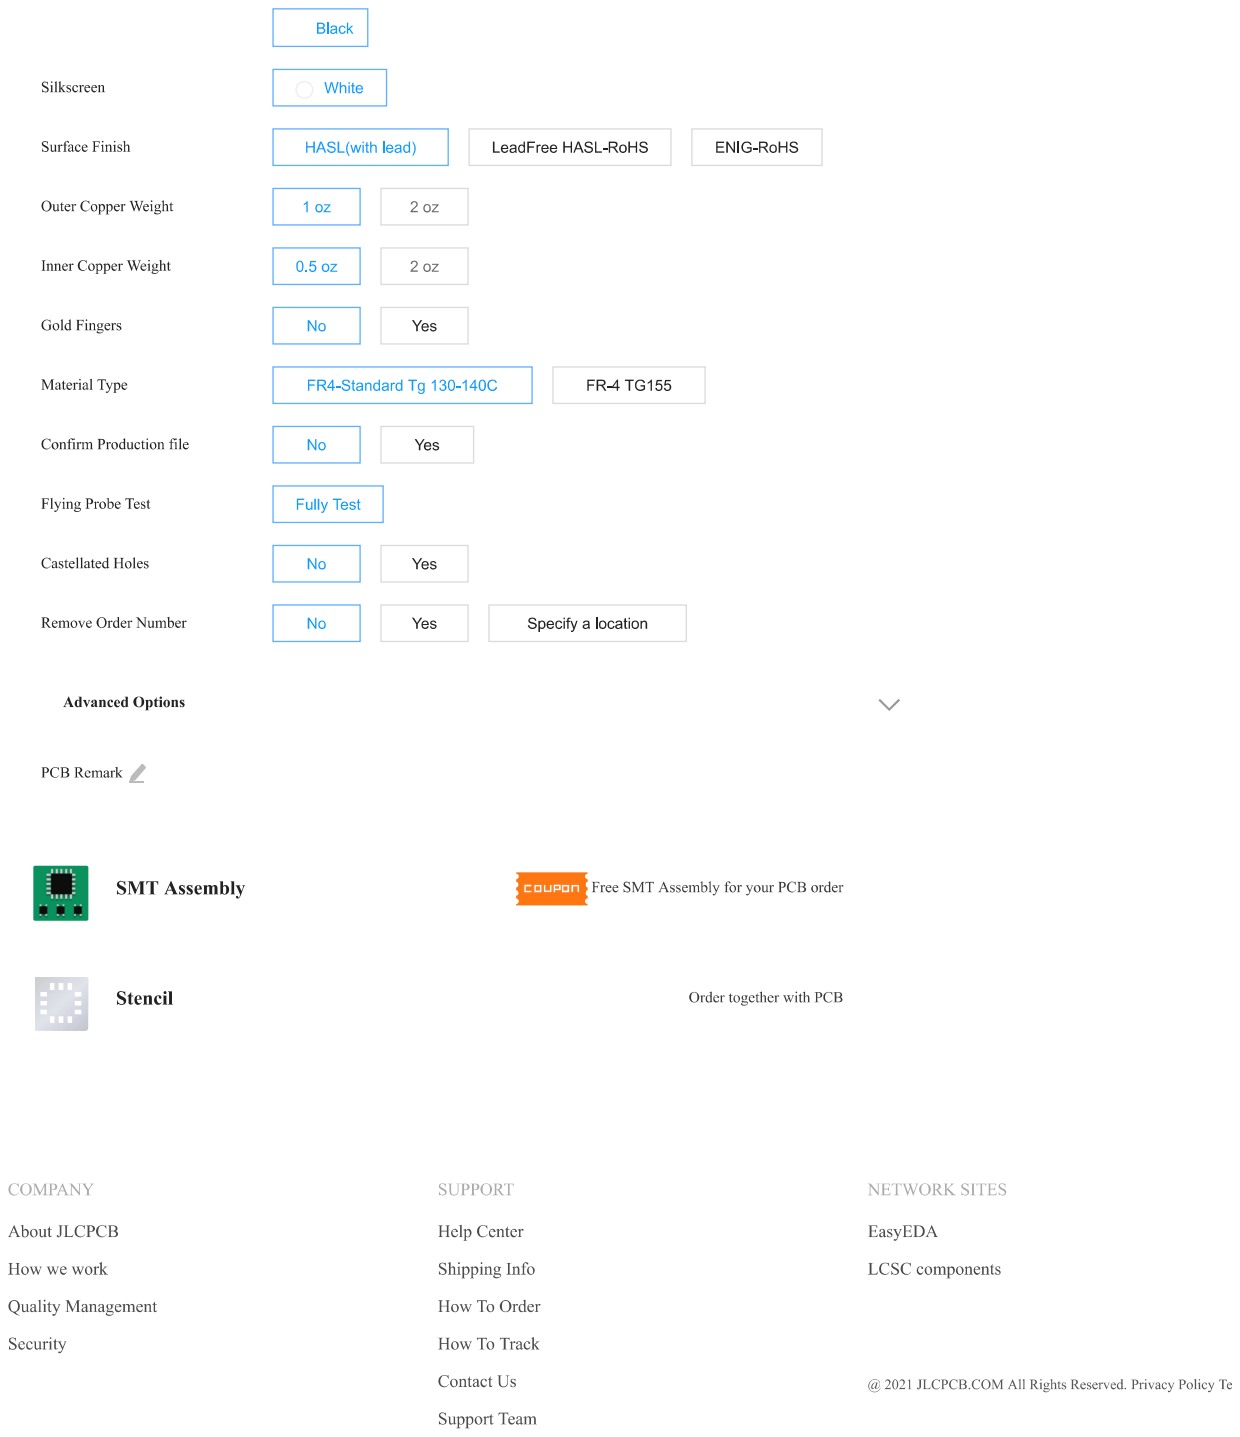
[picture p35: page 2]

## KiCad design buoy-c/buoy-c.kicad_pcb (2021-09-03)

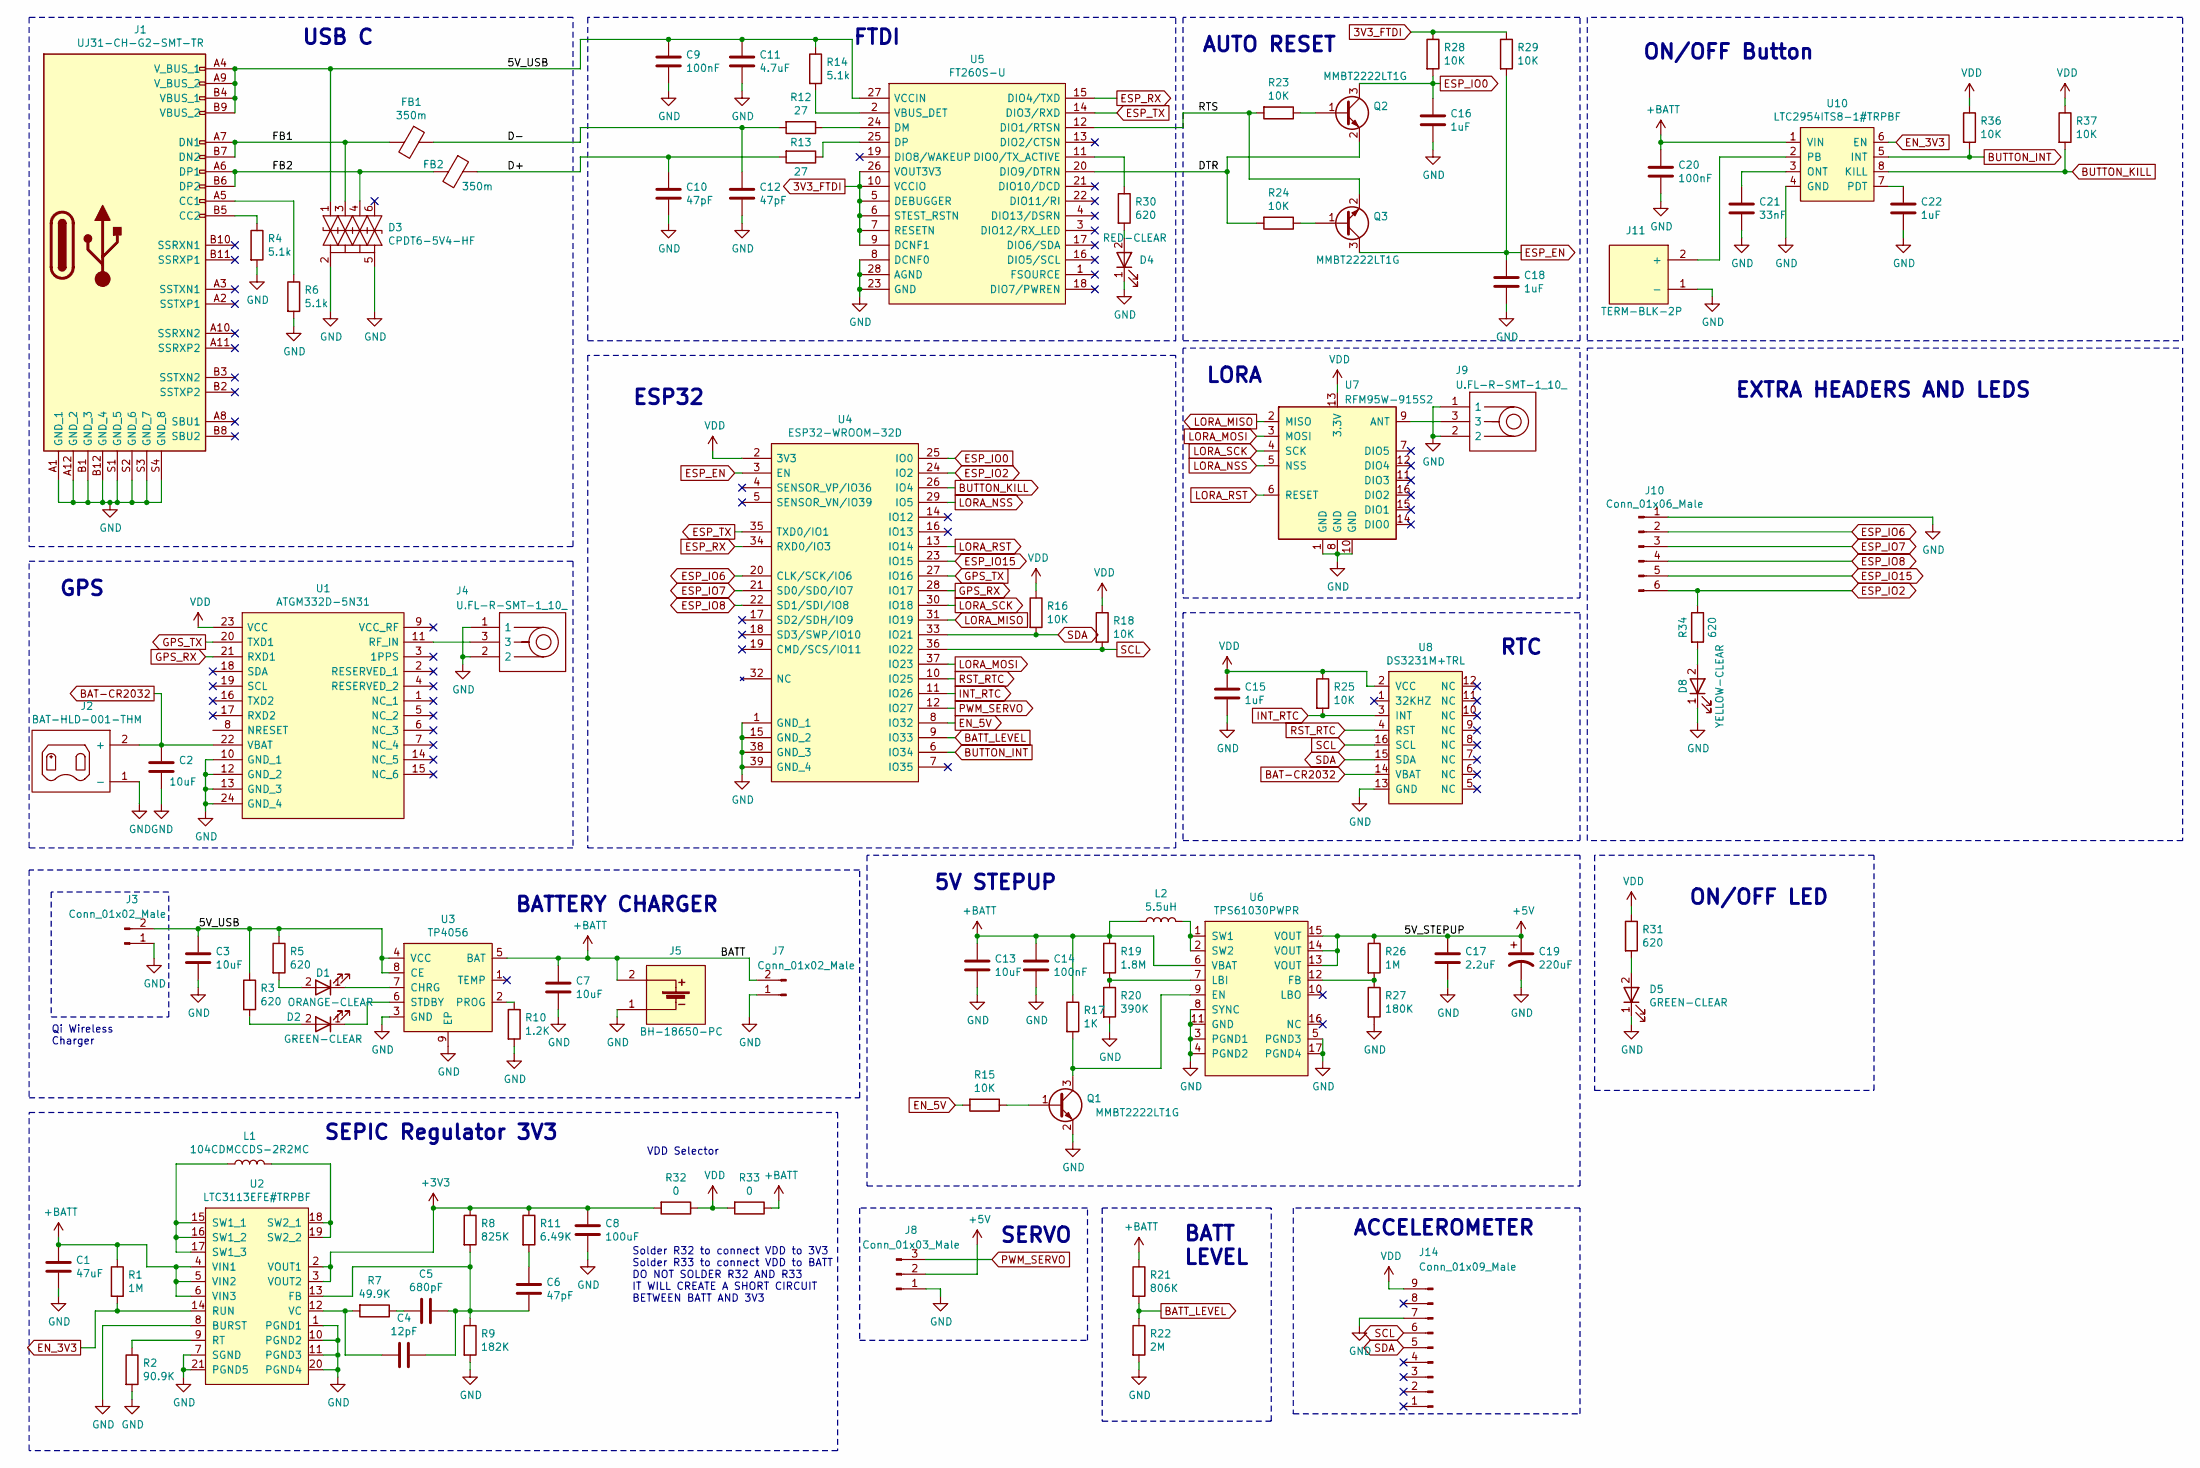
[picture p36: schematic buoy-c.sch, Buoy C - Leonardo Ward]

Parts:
C1: 47uF; C_0805_2012Metric; Manufacturer Part Number JMK212BBJ476MG-T
C2, C3, C7, C13: 10uF; C_0805_2012Metric; Manufacturer Part Number CL21A106KQCLNNC
C4: 12pF; C_0805_2012Metric; Manufacturer Part Number CML0805C0G120JT50V
C5: 680pF; C_0805_2012Metric; Manufacturer Part Number 885012207059
C6, C10, C12: 47pF; C_0805_2012Metric; Manufacturer_Part_Number 885012007014
C8: 100uF; C_1210_3225Metric; Manufacturer Part Number GRM32EE70J107ME15L
C9, C14, C20: 100nF; C_0805_2012Metric; Manufacturer_Part_Number 08055C104KAT2A
C11: 4.7uF; C_0805_2012Metric; Manufacturer_Part_Number CL21A475KQFNNNE
C15, C16, C18, C22: 1uF; C_0805_2012Metric; Manufacturer_Part_Number CL21B105KPFNNNE
C17: 2.2uF; C_0805_2012Metric; Manufacturer Part Number CL21B225KPFNNNE
C19: 220uF; C-2917-7343-Metric; Manufacturer Part Number PCT220/10HK
C21: 33nF; C_0805_2012Metric; Manufacturer Part Number 885012207095
D1: ORANGE-CLEAR; LED_0805_2012Metric; Manufacturer Part Number XZMOK54W-1
D2, D5: GREEN-CLEAR; LED_0805_2012Metric; Manufacturer Part Number 150080VS75000
D3: CPDT6-5V4-HF; SOT-23-6_Handsoldering; Manufacturer_Part_Number CPDT6-5V4-HF
D4: RED-CLEAR; LED_0805_2012Metric; Manufacturer Part Number 150080SS75000
D8: YELLOW-CLEAR; LED_0805_2012Metric; Manufacturer Part Number QTLP630C3TR
FB1, FB2: 350m; R_0805_2012Metric; Manufacturer_Part_Number 2508056017Y0
J1: UJ31-CH-G2-SMT-TR; UJ31CHG2SMTTR; Manufacturer_Part_Number UJ31-CH-G2-SMT-TR
J2: BAT-HLD-001-THM; BATHLD001THM; Manufacturer_Part_Number BAT-HLD-001-THM
J3, J7: Conn_01x02_Male; PinHeader_1x02_P2.54mm_Vertical
J4, J9: U.FL-R-SMT-1_10_; Manufacturer Part Number U.FL-R-SMT-1(10)
J5: BH-18650-PC; BatteryHolder_MPD_BH-18650-PC2; Manufacturer_Part_Number BH-18650-PC
J8: Conn_01x03_Male; PinHeader_1x03_P2.54mm_Vertical
J10: Conn_01x06_Male; PinHeader_1x06_P2.54mm_Vertical
J11: TERM-BLK-2P; TerminalBlock_bornier-2_P5.08mm
J14: Conn_01x09_Male; PinHeader_1x09_P2.54mm_Vertical
L1: 104CDMCCDS-2R2MC; L-11.5x10.3x4; Manufacturer_Part_Number 104CDMCCDS-2R2MC
L2: 5.5uH; L-10.5x10.2x5; Manufacturer Part Number 744325550
Q1, Q2, Q3: MMBT2222LT1G; SOT-23; Manufacturer_Part_Number MMBT2222LT1G
R1, R26: 1M; R_0805_2012Metric; Manufacturer Part Number RMCF0805FT1M00
R2: 90.9K; R_0805_2012Metric; Manufacturer Part Number RMCF0805FT90K9
R3, R5, R30, R31, R34: 620; R_0805_2012Metric; Manufacturer_Part_Number RC0805JR-07620RL
R4, R6, R14: 5.1k; R_0805_2012Metric; Manufacturer_Part_Number RMCF0805FT5K10
R7: 49.9K; R_0805_2012Metric; Manufacturer Part Number RMCF0805FT49K9
R8: 825K; R_0805_2012Metric; Manufacturer Part Number ERA-6AED8253V
R9: 182K; R_0805_2012Metric; Manufacturer Part Number RK73H2ATTD1823F
R10: 1.2K; R_0805_2012Metric_Pad1.20x1.40mm_HandSolder; Manufacturer Part Number RC0805JR-071K2L
R11: 6.49K; R_0805_2012Metric; Manufacturer Part Number ERJ-6ENF6491V
R12, R13: 27; R_0805_2012Metric; Manufacturer_Part_Number RMCF0805FT27R0
R15, R16, R18, R23, R24, R25, R28, R29, R36, R37: 10K; R_0805_2012Metric; Manufacturer_Part_Number CRCW080510K0FKEAC
R17: 1K; R_0805_2012Metric; Manufacturer_Part_Number RMCF0805FT1K00
R19: 1.8M; R_0805_2012Metric; Manufacturer Part Number ERJ-6ENF1804V
R20: 390K; R_0805_2012Metric; Manufacturer Part Number RC0805FR-07390KL
R21: 806K; C_0805_2012Metric; Manufacturer Part Number ERJ-6ENF8063V
R22: 2M; C_0805_2012Metric; Manufacturer Part Number CRCW08052M00FKECC
R27: 180K; R_0805_2012Metric; Manufacturer Part Number RR1220P-184-D
R32, R33: 0; R_0805_2012Metric; Manufacturer Part Number RC0805JR-070RL
U1: ATGM332D-5N31; ATGM332D5N31; Manufacturer_Part_Number ATGM332D-5N31; LCSC C128659
U2: LTC3113EFE#TRPBF; HTSSOP-20-1EP_4.4x6.5mm_P0.65mm_EP3.4x6.5mm_Mask2.75x3.43mm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; Manufacturer Part Number LTC3113EFE#TRPBF
U3: TP4056; ESOP-8; LCSC C382139
U4: ESP32-WROOM-32D; Manufacturer_Part_Number ESP32-WROOM-32D; LCSC C473012
U5: FT260S-U; TSSOP-28_4.4x9.7mm_P0.65mm; Manufacturer_Part_Number FT260S-U
U6: TPS61030PWPR; HTSSOP-16-1EP_4.4x5mm_P0.65mm_EP3.4x5mm_Mask3x3mm_ThermalVi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; Manufacturer Part Number TPS61030PWPR
U7: RFM95W-915S2; HOPERF_RFM9XW_SMD
U8: DS3231M+TRL; SOIC-16W_7.5x10.3mm_P1.27mm; Manufacturer Part Number DS3231M+TRL
U10: LTC2954ITS8-1#TRPBF; TSOT-23-8_HandSoldering; Manufacturer Part Number LTC2954ITS8-1#TRPBF

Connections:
3V3_FTDI: R28.1, R29.1, U5.5 (DEBUGGER), U5.6 (STEST_RSTN), U5.7 (RESETN), U5.9 (DCNF1), U5.10 (VCCIO), U5.26 (VOUT3V3)
+3V3: C8.1, R8.1, R11.1, R32.2, U2.2 (VOUT1), U2.3 (VOUT2)
+5V: C17.1, C19.1, J8.2, R26.1, U6.13 (VOUT), U6.14 (VOUT), U6.15 (VOUT)
+BATT: C1.1, C7.1, C13.1, C14.1, C20.1, J5.2 (+), J7.2, L2.1, R1.1, R17.1, R19.1, R21.1, R33.1, U2.4 (VIN1), U2.5 (VIN2), U2.6 (VIN3), U3.5 (BAT), U6.6 (VBAT), U10.1 (VIN)
/5V_USB: C3.1, C9.1, C11.1, D3.1, J1.A4 (V_BUS_1), J1.A9 (V_BUS_2), J1.B4 (VBUS_1), J1.B9 (VBUS_2), J3.2, R3.1, R5.1, R14.1, U3.4 (VCC), U3.8 (CE), U5.27 (VCCIN)
/D+: C10.1, FB2.1, R13.2
/D-: C12.1, FB1.1, R12.2
/DTR: Q2.2 (E), R24.2, U5.20 (DIO9/DTRN)
/FB1: D3.3, FB1.2, J1.A7 (DN1), J1.B7 (DN2)
/FB2: D3.4, FB2.2, J1.A6 (DP1), J1.B6 (DP2)
/RTS: Q3.2 (E), R23.2, U5.12 (DIO1/RTSN)
BAT-CR2032: C2.1, J2.2 (+), U1.22 (VBAT), U8.14 (VBAT)
BATT_LEVEL: R21.2, R22.1, U4.9 (IO33)
BUTTON_INT: R36.2, U4.6 (IO34), U10.5 (INT)
BUTTON_KILL: R37.2, U4.26 (IO4), U10.8 (KILL)
EN_3V3: R1.2, U2.14 (RUN), U10.6 (EN)
EN_5V: R15.2, U4.8 (IO32)
ESP_EN: C18.1, Q3.3 (C), R29.2, U4.3 (EN)
ESP_IO0: C16.1, Q2.3 (C), R28.2, U4.25 (IO0)
ESP_IO2: J10.6, R34.1, U4.24 (IO2)
ESP_IO6: J10.2, U4.20 (CLK/SCK/IO6)
ESP_IO7: J10.3, U4.21 (SD0/SDO/IO7)
ESP_IO8: J10.4, U4.22 (SD1/SDI/IO8)
ESP_IO15: J10.5, U4.23 (IO15)
ESP_RX: U4.34 (RXD0/IO3), U5.15 (DIO4/TXD)
ESP_TX: U4.35 (TXD0/IO1), U5.14 (DIO3/RXD)
GND: C1.2, C2.2, C3.2, C7.2, C8.2, C9.2, C10.2, C11.2, C12.2, C13.2, C14.2, C15.2, C16.2, C17.2, C18.2, C19.2, C20.2, C21.2, C22.2, D3.2, D3.5, D4.1 (K), D5.1 (K), D8.1 (K), J1.A1 (GND_1), J1.A12 (GND_2), J1.B1 (GND_3), J1.B12 (GND_4), J1.S1 (GND_5), J1.S2 (GND_6), J1.S3 (GND_7), J1.S4 (GND_8), J2.1 (-), J3.1, J4.1, J4.2, J5.1 (-), J7.1, J8.1, J9.1, J9.2, J10.1, J11.1 (-), J14.7, Q1.2 (E), R2.2, R4.2, R6.2, R9.2, R10.2, R20.2, R22.2, R27.2, U1.10 (GND_1), U1.12 (GND_2), U1.13 (GND_3), U1.24 (GND_4), U2.1 (PGND1), U2.7 (SGND), U2.8 (BURST), U2.10 (PGND2), U2.11 (PGND3), U2.20 (PGND4), U2.21 (PGND5), U3.3 (GND), U3.9 (EP), U4.1 (GND_1), U4.15 (GND_2), U4.38 (GND_3), U4.39 (GND_4), U5.8 (DCNF0), U5.23 (GND), U5.28 (AGND), U6.3 (PGND1), U6.4 (PGND2), U6.5 (PGND3), U6.8 (SYNC), U6.11 (GND), U6.17 (PGND4), U7.1 (GND), U7.8 (GND), U7.10 (GND), U8.13 (GND), U10.4 (GND)
GPS_RX: U1.21 (RXD1), U4.28 (IO17)
GPS_TX: U1.20 (TXD1), U4.27 (IO16)
INT_RTC: R25.2, U4.11 (IO26), U8.3 (INT)
LORA_MISO: U4.31 (IO19), U7.2 (MISO)
LORA_MOSI: U4.37 (IO23), U7.3 (MOSI)
LORA_NSS: U4.29 (IO5), U7.5 (NSS)
LORA_RST: U4.13 (IO14), U7.6 (RESET)
LORA_SCK: U4.30 (IO18), U7.4 (SCK)
unnamed: C4.1, C5.1, C6.2, R8.2, R9.1, U2.13 (FB)
unnamed: C4.2, R7.2, U2.12 (VC)
unnamed: C5.2, R7.1
unnamed: C6.1, R11.2
unnamed: C21.1, U10.3 (ONT)
unnamed: C22.1, U10.7 (PDT)
unnamed: D1.1 (K), U3.7 (CHRG)
unnamed: D1.2 (A), R5.2
unnamed: D2.1 (K), U3.6 (STDBY)
unnamed: D2.2 (A), R3.2
unnamed: D4.2 (A), R30.2
unnamed: D5.2 (A), R31.2
unnamed: D8.2 (A), R34.2
unnamed: J1.A5 (CC1), R6.1
unnamed: J1.B5 (CC2), R4.1
unnamed: J4.3, U1.11 (RF_IN)
unnamed: J9.3, U7.9 (ANT)
unnamed: J11.2 (+), U10.2 (PB)
unnamed: L1.1, U2.15 (SW1_1), U2.16 (SW1_2), U2.17 (SW1_3)
unnamed: L1.2, U2.18 (SW2_1), U2.19 (SW2_2)
unnamed: L2.2, U6.1 (SW1), U6.2 (SW2)
unnamed: Q1.1 (B), R15.1
unnamed: Q1.3 (C), R17.2, U6.9 (EN)
unnamed: Q2.1 (B), R23.1
unnamed: Q3.1 (B), R24.1
unnamed: R2.1, U2.9 (RT)
unnamed: R10.1, U3.2 (PROG)
unnamed: R12.1, U5.24 (DM)
unnamed: R13.1, U5.25 (DP)
unnamed: R14.2, U5.2 (VBUS_DET)
unnamed: R19.2, R20.1, U6.7 (LBI)
unnamed: R26.2, R27.1, U6.12 (FB)
unnamed: R30.1, U5.11 (DIO0/TX_ACTIVE)
PWM_SERVO: J8.3, U4.12 (IO27)
RST_RTC: U4.10 (IO25), U8.4 (RST)
SCL: J14.6, R18.2, U4.36 (IO22), U8.16 (SCL)
SDA: J14.5, R16.2, U4.33 (IO21), U8.15 (SDA)
VDD: C15.1, J14.9, R16.1, R18.1, R25.1, R31.1, R32.1, R33.2, R36.1, R37.1, U1.23 (VCC), U4.2 (3V3), U7.13 (3.3V), U8.2 (VCC)

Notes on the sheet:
USB C
FTDI
AUTO RESET
LORA
GPS
RTC
ESP32
BATTERY CHARGER
Qi Wireless Charger
SEPIC Regulator 3V3
VDD Selector
Solder R32 to connect VDD to 3V3 Solder R33 to connect VDD to BATT DO NOT SOLDER R32 AND R33 IT WILL CREATE A SHORT CIRCUIT BETWEEN BATT AND 3V3
5V STEPUP
SERVO
BATT LEVEL
ACCELEROMETER
ON/OFF Button
ON/OFF LED
EXTRA HEADERS AND LEDS

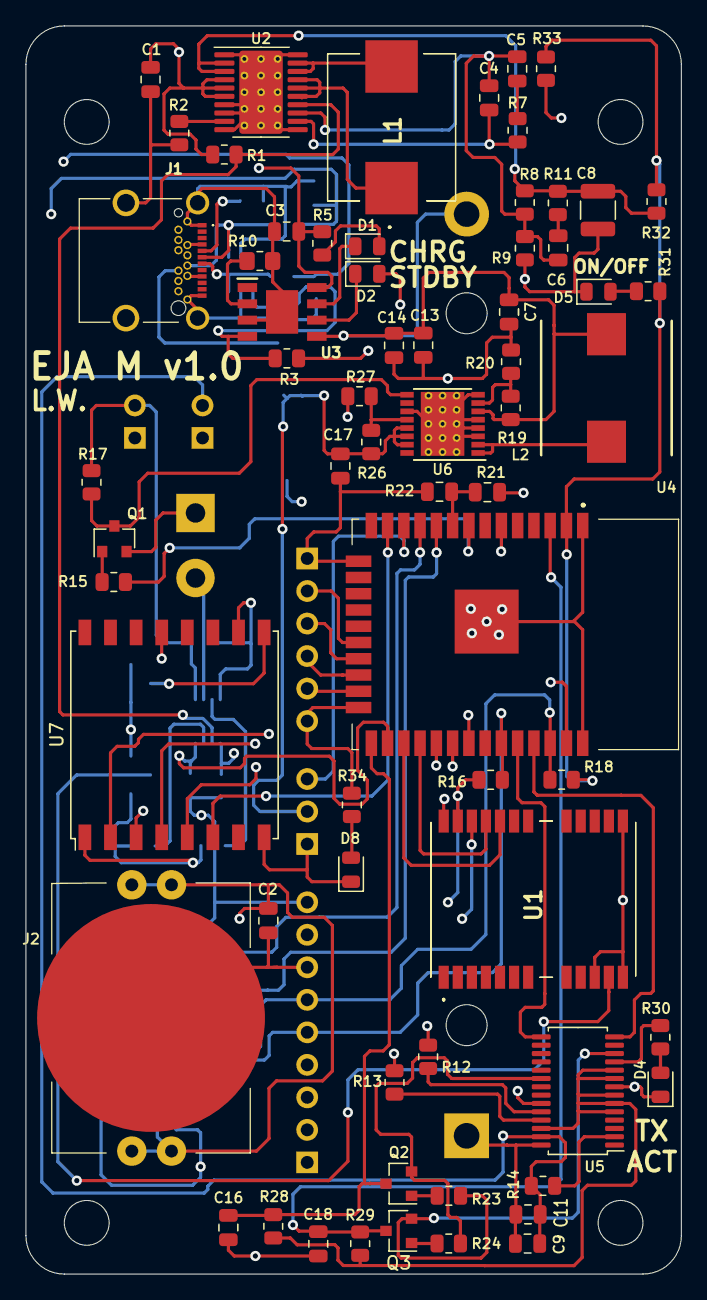
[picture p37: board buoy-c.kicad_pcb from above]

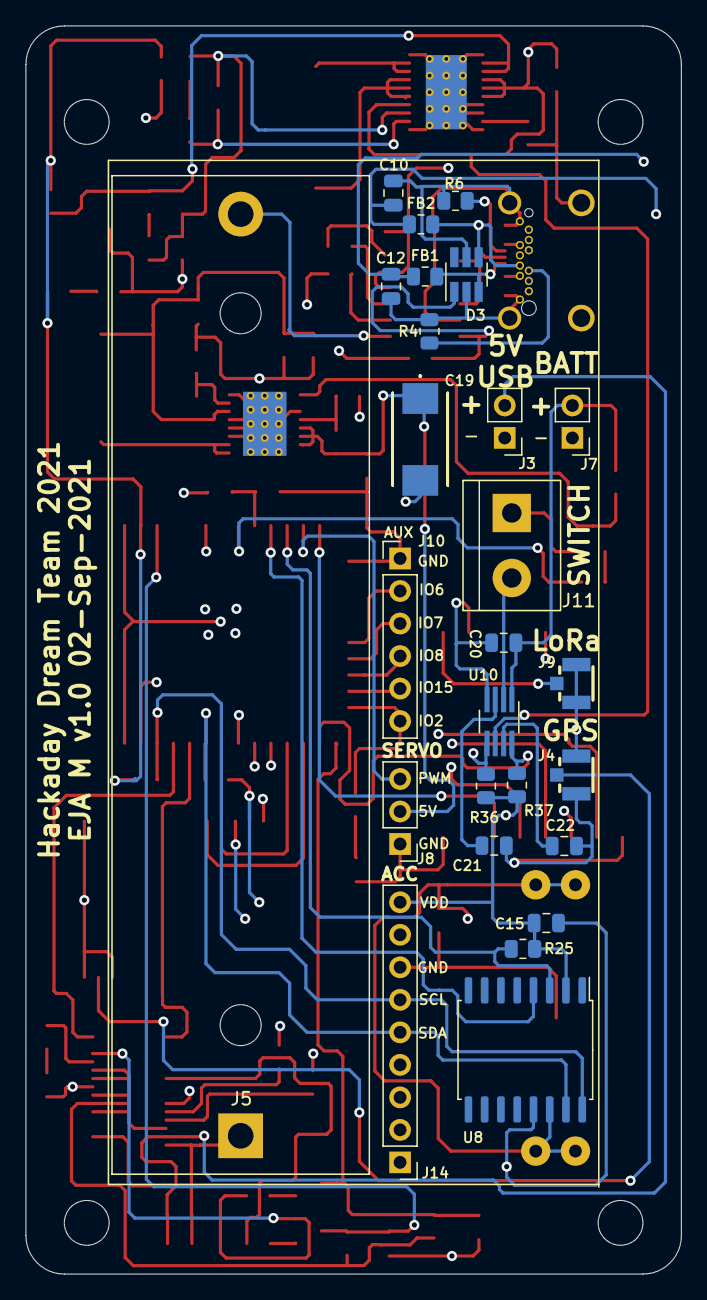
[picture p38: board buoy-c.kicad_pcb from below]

Board: 4 copper layers, 51.2 x 97.5 mm, 91 parts (26 on the bottom side), 73 nets.

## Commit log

2021-08-22 Added USB C, FTDI, auto reset, LoRa, GPS and ESP32 to the schematic
    [ESP32-WROOM-32D.stp, UJ31-CH-G2-SMT-TR.stp, buoy-c.kicad_pcb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]
2021-08-27 Added regulator, stepup, accelerometer, battery charger, servo and battery measurement
    [buoy-c.sch]
2021-08-27 Added schematic
2021-08-30 Defined board shape, placed components in the PCB
    [ATGM332D-5N31.stl, ATGM332D-5N31.stp, BAT-HLD-001-THM.stp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]
2021-08-31 Placed components in the PCB
    [buoy-c.kicad_pcb, buoy-c.sch]
2021-09-02 Finished routing, solved unconnected
    [buoy-c.kicad_pcb, buoy-c.sch]
2021-09-02 Solved important errors
    [buoy-c.kicad_pcb]
2021-09-02 Added missing 3d Models
    [ECGSY0G471R.stp, TP4056.stp, buoy-c.kicad_pcb]
2021-09-03 Added gerber files
    [BOM DigiKey - Final PCB.xlsx, BOM LCSC - Final PCB.xlsx, board.dxf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]
2021-10-13 Added images
    [buoy-c.sch]
2021-10-14 Added BOM
2021-10-14 Added BOM to the menu
